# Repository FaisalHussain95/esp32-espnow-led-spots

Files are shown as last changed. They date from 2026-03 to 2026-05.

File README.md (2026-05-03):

# DIY Smart LED Spot Replacement

Replacing 13 cheap 220V ceiling spots with custom COB LED units — dimmable, Home Assistant integrated, actively cooled, and wirelessly controlled over ESP-NOW.

```mermaid
graph LR
    HA[🏠 Home Assistant]

    subgraph wifi_net[IoT WiFi network]
        BR[WiFi Bridge\nESP32-C3 SuperMini\nWiFi mode]
    end

    subgraph espnow_net[ESP-NOW ch11 — AES-128 — no WiFi]
        MA[Master\nESP32-C3 SuperMini]
        S1[Spot 1\nESP32-C3]
        S2[Spot 2\nESP32-C3]
        SN[Spot 3…13\nESP32-C3]
        MA <-->|ESP-NOW| S1
        MA <-->|ESP-NOW| S2
        MA <-->|ESP-NOW| SN
    end

    HA <-->|MQTT| BR
    BR <-->|UART 115200| MA
```

---

## The problem

I have 13 recessed spots installed across my ceiling. They were cheap 220V AC units with no heatsink — just a bare aluminium PCB glued to a plastic shell.

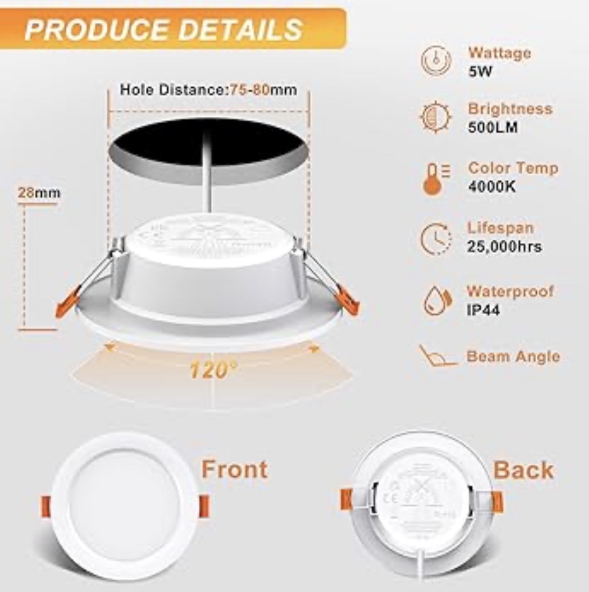
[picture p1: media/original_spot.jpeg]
Original spot


Opening one up tells the whole story: the driver circuit runs directly off mains voltage with no thermal management whatsoever.

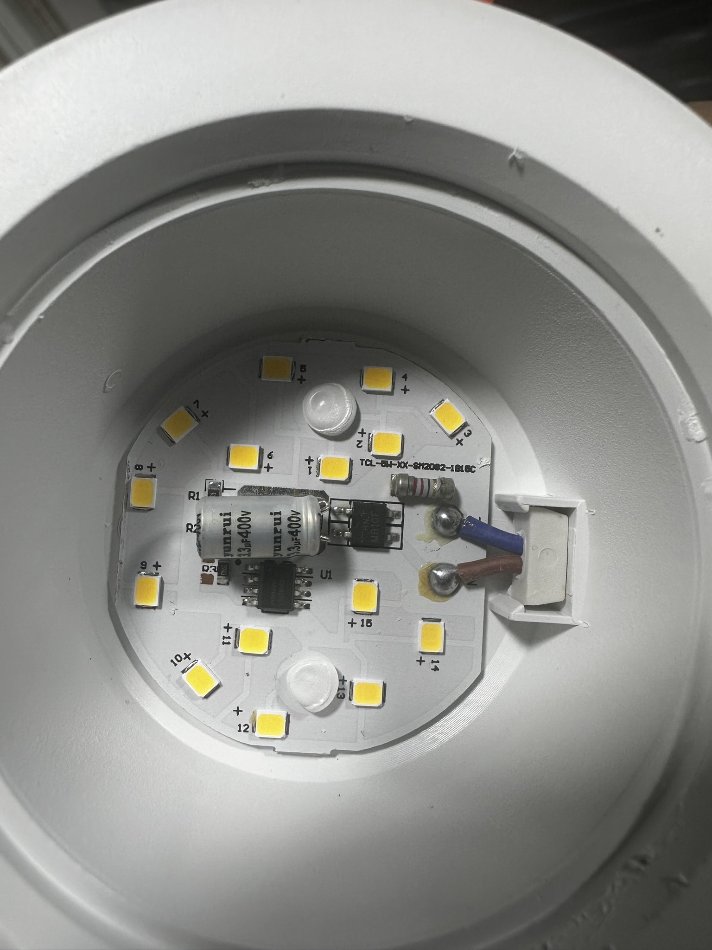
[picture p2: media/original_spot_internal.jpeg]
Original spot internals


After about 5000 hours one by one they started dying from overheating. Rather than buying the same thing again, I decided to rebuild them properly.

---

## The goals

- **Reuse the existing shells** — no new ceiling holes
- **Use COB LEDs from stock** — 5W COB with a proper heatsink and active cooling to make them last
- **Dimmable** — the original spots were on/off only
- **Home Assistant integration** — via MQTT
- **OTA updates** — to add effects or fix bugs without a ladder (we already added a pulse effect and smooth fade in/out)
- **No per-spot WiFi** — 13 devices on the IoT network is too much; ESP-NOW keeps them off WiFi entirely

---

## Why not a simpler controller?

The ESP32 is overkill for dimming a light, I know. The constraint was the existing wiring in the ceiling: when it was first installed nobody thought about future upgrades, so we are stuck with the cables already there. Running a new PWM signal cable through the ceiling was not feasible. We needed a device that could receive wireless commands and that I already knew how to program — hence ESP32 + ESP-NOW.

---

## Power: from 220V mains to 24V DC

The original spots each had their own mains driver. The replacement approach uses a single shared 24V DC rail for all spots.

**Power supply: TRACO TSP 180-124 — 24V / 180W**

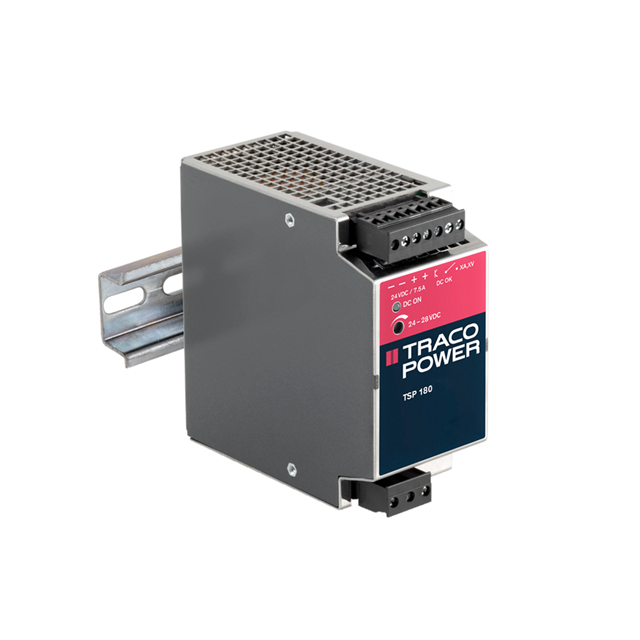
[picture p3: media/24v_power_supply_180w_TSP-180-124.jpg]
Power supply


The supply sits centrally, with two cable runs of 15m each covering all spots.

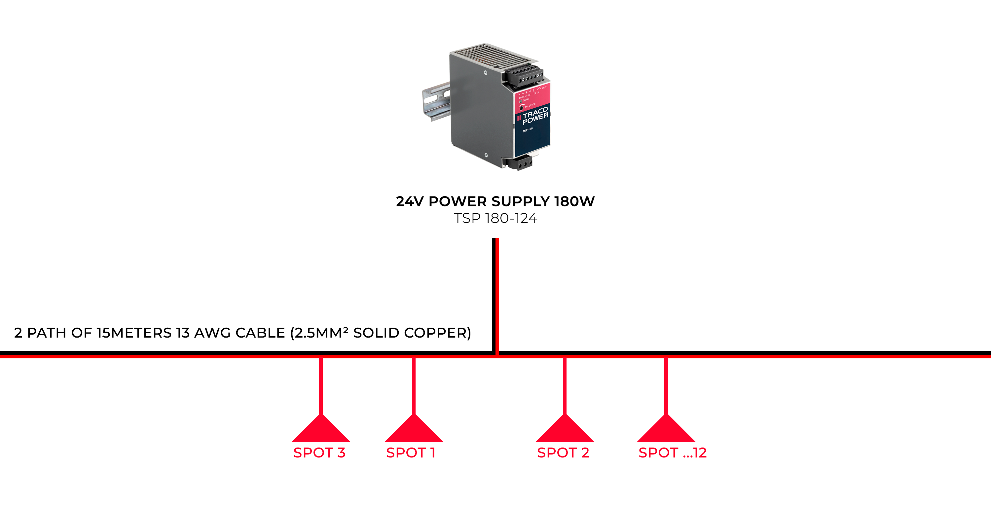
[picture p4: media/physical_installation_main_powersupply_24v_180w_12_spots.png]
Wiring diagram


### Cable sizing

Existing cable: 2.5mm² solid copper (13 AWG), already in the ceiling (previously carrying 220V).

- COB LED: ~7W max, running at PWM 160/255 → ~4.4W effective
- ESP32-C3: ~0.5W
- Budget per spot: **~12W to be safe** → total load: 13 × 12W = **156W / 24V = 6.5A** across the full 30m run
- Per 15m path: **max ~3A**

Using a [wire size calculator](https://www.omnicalculator.com/physics/wire-size) with 3A over 15m and a 10% voltage drop tolerance, 2.5mm² is sufficient. The cable was already there — we just repurposed it from 220V AC to 24V DC.

---

## The replacement unit

Each spot gets a self-contained module: COB LED + heatsink + fan + NTC + ESP32-C3 + custom PCB.

### COB LED on heatsink

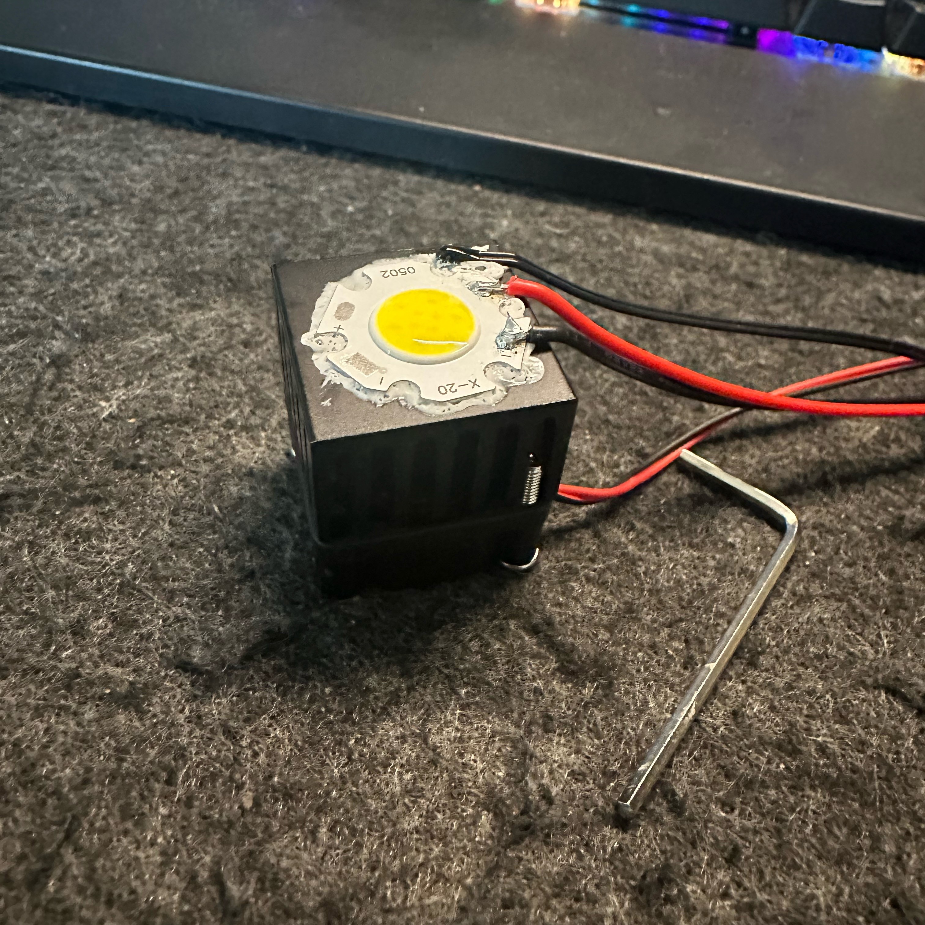
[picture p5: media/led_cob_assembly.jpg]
COB on heatsink


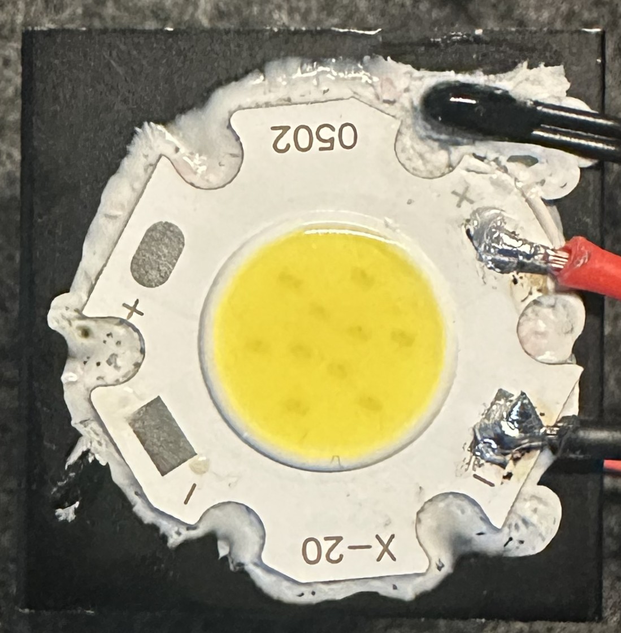
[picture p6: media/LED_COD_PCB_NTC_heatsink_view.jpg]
COB top view


### With fan mounted

The 25×25mm fan sits on top of the heatsink. It is 5V PWM-controlled, kicks in above 45°C and cuts off below 40°C. At normal brightness the fan rarely runs.

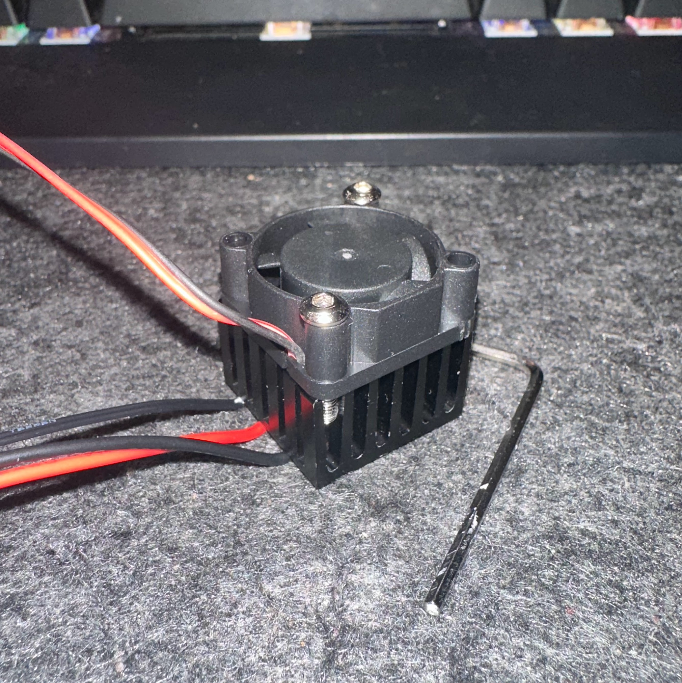
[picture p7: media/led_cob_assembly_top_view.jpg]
Assembly with fan


### NTC thermal protection

An MF52 10kΩ NTC is mounted against the heatsink. The firmware reads it every second and applies progressive PWM throttling at 60°C, a hard floor at 75°C, and alerts the master controller at 85°C.

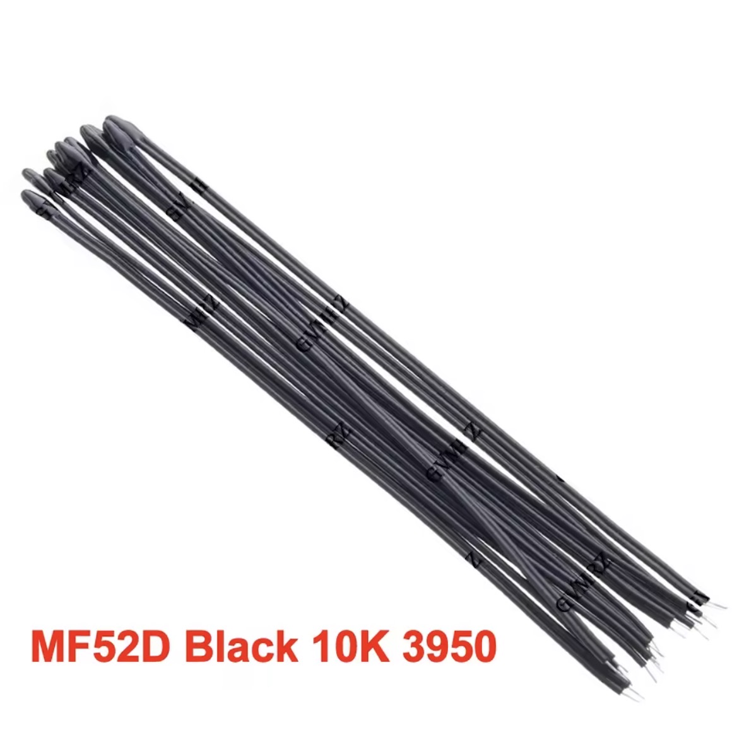
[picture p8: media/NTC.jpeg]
NTC sensor


---

## The PCB

The driver electronics sit on a custom KiCad board that fits inside the spot shell. It carries the MP1584 buck converter (24V → 3.3V), PT4115 LED driver, fan MOSFET, NTC input, and the ESP32-C3 SuperMini.

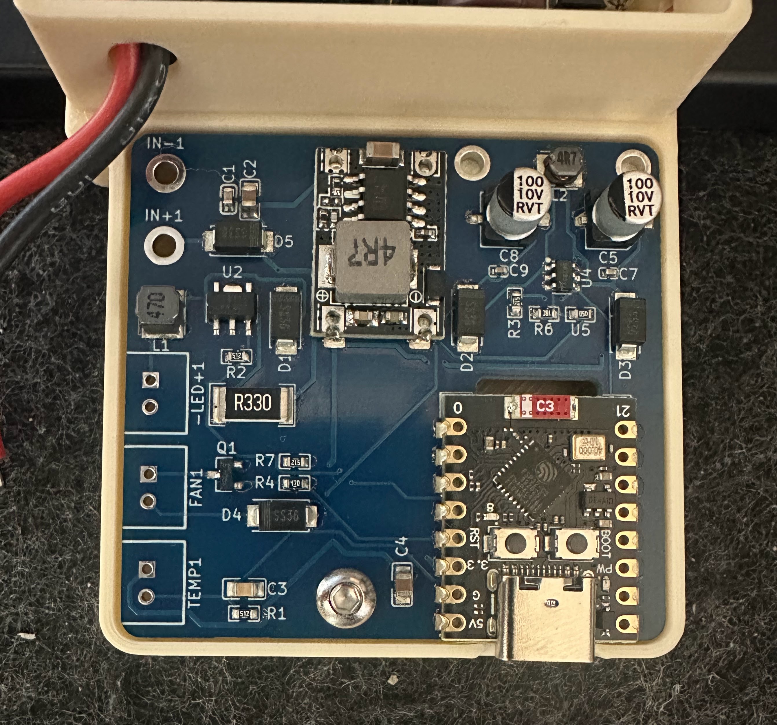
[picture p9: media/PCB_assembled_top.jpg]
PCB top


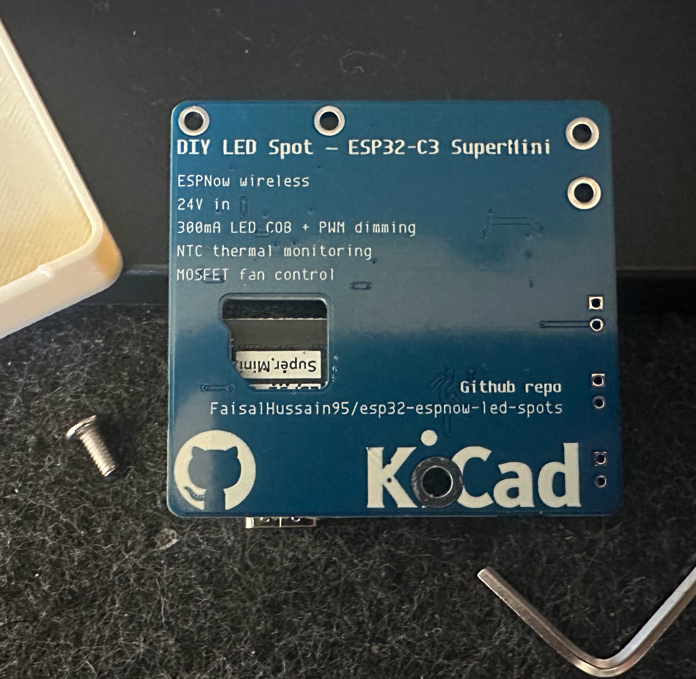
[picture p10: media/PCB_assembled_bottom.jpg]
PCB bottom


**Manufacturing files for JLCPCB** (Gerbers, BOM, CPL) are in [kicad/diy_led_spot/v4/](kicad/diy_led_spot/v4/). The KiCad project itself is in [kicad/diy_led_spot/](kicad/diy_led_spot/).

---

## How it works

Each spot is an ESP32-C3 node. An ESP32-C3 SuperMini acts as master. A second ESP32-C3 SuperMini bridges MQTT to the master over UART. The spots never touch WiFi during normal operation — everything runs over ESP-NOW on a dedicated channel.

```mermaid
sequenceDiagram
    participant HA as Home Assistant
    participant BR as WiFi Bridge<br/>(ESP32-C3 SuperMini)
    participant MA as Master<br/>(ESP32-C3 SuperMini)
    participant SP as Spot × N<br/>(ESP32-C3)
    participant GH as GitHub Releases<br/>(OTA)

    note over SP,MA: ── Boot handshake (ESP-NOW ch11, AES-128) ──
    SP->>MA: MSG_HELLO {spot_id, fw_version}
    alt version OK
        MA->>SP: MSG_ACK
    else version outdated
        MA->>SP: MSG_REJECT + MSG_OTA_NOW {target_version}
        SP->>GH: HTTP GET slave_c3_supermini_vN.bin
        GH-->>SP: firmware binary → flash & reboot
    end

    note over MA: Master reboot → rediscover all spots
    MA->>SP: MSG_WHOIS (broadcast)
    SP->>MA: MSG_HELLO (re-announce)

    note over HA,SP: ── Normal operation ──
    HA->>BR: MQTT homeassistant/led_spots/{id}/set<br/>{"state":"ON","brightness":200}
    BR->>MA: UART frame 0xAA 0x01 spot_id bri cmd 0x55
    MA->>SP: MSG_CMD {spot_id, CMD_TURN_ON, brightness}

    SP-->>MA: MSG_STATUS every 10 s<br/>{spot_id, brightness, temp°C, thermal_state, is_on}
    MA-->>BR: UART frame 0xAA 0x02 spot_id bri temp_hi temp_lo thermal 0x55
    BR-->>HA: MQTT homeassistant/led_spots/{id}/state<br/>{"state":"ON","brightness":200,"temperature":42.3}

    note over SP: ── Thermal protection (on-spot) ──
    SP->>SP: NTC read every 1 s<br/>60°C → throttle PWM<br/>85°C → PWM floor + alert
    SP-->>MA: MSG_STATUS {thermal_state: critical}

    note over HA,GH: ── OTA triggered from HA ──
    HA->>BR: MQTT homeassistant/led_spots/ota/set {"version":30}
    BR->>MA: UART frame 0xAA 0x03 target_version 0x55
    MA->>SP: MSG_OTA_NOW {target_version} (broadcast)
    SP->>GH: HTTP GET slave_c3_supermini_v30.bin
    GH-->>SP: firmware binary → flash & reboot
```

For the full technical details, wiring, firmware architecture, and PCB design see [TECHNICAL.md](TECHNICAL.md).

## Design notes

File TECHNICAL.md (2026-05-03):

# DIY LED Spot Controller

DIY replacement of 10× 220VAC LED spots with custom COB LED + ESP32 controller units.
Each spot has an isolated AC/DC converter, constant-current LED driving via PT4115, NTC thermal monitoring,
and encrypted ESP-NOW wireless control — no WiFi router required for the spots.

---

## System Architecture

```
Home Assistant
     │
     │ MQTT (WiFi)
     │
┌────┴──────────────┐
│  WiFi Bridge      │  ESP32-C3 SuperMini
│                   │  WiFi + MQTT ↔ UART bridge
└────────┬──────────┘
         │ UART1 binary frames (115200 baud)
         │ GPIO6(TX) → GPIO7(RX) (Master)
         │ GPIO7(RX) ← GPIO6(TX) (Master)
┌────────┴──────────┐
│  Master Node      │  ESP32-C3 SuperMini
│                   │  ESP-NOW only
│                   │  Optional: 0.91" SSD1306 128×32 OLED (SDA=GPIO1, SCL=GPIO0)
└────────┬──────────┘
         │ ESP-NOW (PMK encrypted, 2.4GHz)
         │
    ┌────┴────┐
    │         │
  Spot 1   Spot 2 … Spot 10
 ESP32-C3  ESP32-C3  ESP32-C3
 SuperMini SuperMini SuperMini
```

The master (ESP32-C3 SuperMini) runs ESP-NOW only — no WiFi.
The WiFi bridge handles MQTT/HA and translates commands to/from UART binary frames.
This separation avoids ESP-NOW peer drops caused by WiFi channel switching.

---

## Firmware Structure

```
spot_firmware/          — One binary per spot (ESP32-C3 SuperMini)
├── platformio.ini
└── src/
    ├── main.cpp              # Setup, loop, command handler, thermal policy, status LED
    ├── config.h              # Pin defines, thresholds, SPOT_ID, packet structs — edit per unit
    ├── thermal.h/.cpp        # NTC read (32× oversampling), Steinhart-Hart, throttle logic
    ├── dimming.h/.cpp        # LEDC init, setBrightness(), fadeTo()
    ├── espnow_manager.h/.cpp # ESP-NOW init, PMK encryption, HELLO handshake, send/receive
    ├── provisioning.h/.cpp   # PMK + WiFi creds from build_flags → NVS (first boot only)
    └── ota.h/.cpp            # HTTP OTA update from GitHub release URL (5 retries)

master_firmware/        — One binary for the master node (ESP32-C3 SuperMini)
├── platformio.ini
└── src/
    ├── main.cpp              # ESP-NOW master, OLED display, serial CLI, UART bridge
    └── config.h              # Spot MAC table, packet structs, UART pin defines

wifi_bridge_firmware/   — One binary for the WiFi bridge (ESP32-C3 SuperMini)
├── platformio.ini
└── src/
    ├── main.cpp              # WiFi + MQTT ↔ UART bridge, HA MQTT Discovery
    └── config.h              # UART pins, MQTT topic prefix, frame constants
```

**Porting a spot to a new unit:** only change `SPOT_ID` (0x01–0x0A) in `spot_firmware/src/config.h`. The master MAC is read from NVS via `provisioning_get_master_mac()` — it is no longer hardcoded.

---

## Hardware (per spot)

### Power Chain
```
220VAC ──► HLK-PM24 ──► 24VDC ──► PT4115 (CC driver) ──► COB LED (5W)
                    │
                    └──► MP1584 buck ──► 3.3VDC ──► ESP32-C3 SuperMini
                                                          │
                                                     GPIO10 (PWM 10kHz)
                                                          │
                                                     PT4115 DIM pin
```

The HLK-PM24 provides an isolated 24V rail.
The PT4115 is a constant-current buck LED driver — current is set by Rsense, not firmware.
PWM on the DIM pin dims the LED by modulating the driver enable signal.

### Components

| Component | Value / Model | Purpose |
|---|---|---|
| AC/DC converter | HLK-PM24 | 220VAC → 24VDC, 1A, isolated |
| Buck converter | MP1584 module | 24V → 3.3V for ESP32 |
| Microcontroller | ESP32-C3 SuperMini | Control + ESP-NOW wireless |
| LED driver | PT4115 | Constant-current buck driver, DIM pin PWM |
| Current sense | 0.33Ω 1W | Iout = 0.1V / 0.33Ω ≈ 303mA |
| Freewheeling diode | 1N4007 | Across COB LED (buck topology) |
| Thermal sensor | NTC 10kΩ 0402, B=3950 | Mounted on COB PCB |
| NTC divider | 5.1kΩ fixed to GND | NTC on 3.3V side |
| ADC filter | 100nF ceramic to GND | On ADC signal wire, noise filtering |

### PT4115 Wiring
```
24V ──► PT4115 VIN
        PT4115 SW ──► inductor ──► COB+ ──► COB- ──► PT4115 CS ──► 0.33Ω ──► GND
ESP32 GPIO10 ──► PT4115 DIM   (PWM 10kHz, 0–100% duty = 0–full current)
```

### NTC Wiring
```
3.3V
 │
[NTC 10kΩ]          ← mounted on COB PCB, wired back to ESP32 via cable
 │
 ├──► GPIO3 (ADC1_CH3)
 │         │
 │       [100nF] ──► GND    ← on ESP32 PCB end, filters cable noise
 │
[5.1kΩ]
 │
GND
```

- NTC on the 3.3V side; formula: `r_ntc = R_pullup × (ADC_MAX − adc) / adc`
- 32× ADC oversampling + Steinhart-Hart Beta equation
- **ADC quirk (ESP32 Arduino core):** call a dummy `analogRead(pin)` before `analogSetPinAttenuation()` — otherwise attenuation doesn't apply and the ADC reads 0

### GPIO Pin Mapping

#### ESP32-C3 SuperMini (spot node — final)
| Function | GPIO | Notes |
|---|---|---|
| PWM → PT4115 DIM | GPIO10 | LEDC 10kHz 8-bit, no ADC, no strapping conflict |
| NTC ADC | GPIO3 | ADC1_CH3 — safe with ESP-NOW active (ADC1 only) |
| Status LED | GPIO8 | Onboard blue LED, **active LOW** |

#### Master / Bridge (ESP32-C3 SuperMini)
| Function | GPIO | Notes |
|---|---|---|
| UART1 TX (to bridge/master) | GPIO6 | Cross-connected TX→RX |
| UART1 RX (from bridge/master) | GPIO7 | Cross-connected RX←TX |
| OLED SDA (master only, optional) | GPIO1 | I2C, 0.91" SSD1306 128×32 |
| OLED SCL (master only, optional) | GPIO0 | I2C |

#### ESP32 WROVER (prototype only)
| Function | GPIO | Notes |
|---|---|---|
| PWM → PT4115 DIM | GPIO18 | LEDC 10kHz 8-bit |
| NTC ADC | GPIO34 | Input-only ADC1 channel |
| Status LED | GPIO2 | Onboard LED, active HIGH |

---

## Thermal Protection

### PWM limits
| Constant | Value | Reason |
|---|---|---|
| `PWM_MAX` | 160 | ~5W operating point for COB LED |
| `PWM_MIN_FLOOR` | 20 | Minimum allowed in throttle/critical states |

The master can send brightness 0–255, but the spot clamps the output to `PWM_MAX` (160) before passing it to the LEDC peripheral.

### Thermal states

| Temperature | State | Action |
|---|---|---|
| < 60°C | NORMAL | Full PWM authority (capped at `PWM_MAX`=160) |
| 60–75°C | THROTTLING | Linear ramp-down from requested brightness to `PWM_MIN_FLOOR` (20) |
| 75–85°C | THROTTLING | Hard floor: output clamped to `PWM_MIN_FLOOR` (20) |
| > 85°C | CRITICAL | Clamped to `PWM_MIN_FLOOR` + immediate ESP-NOW alert to master |

### Status LED patterns (GPIO8, active LOW)
| State | Pattern |
|---|---|
| NORMAL | 1s on / 2s off |
| THROTTLING | Solid ON |
| CRITICAL | 100ms on / 100ms off (rapid blink) |
| NTC fault | CRITICAL pattern |

---

## ESP-NOW Protocol

### Encryption
All unicast packets are PMK-encrypted (AES-128).
The PMK is set in `platformio.ini` `build_flags`, written to NVS on first boot, and survives OTA flashes.
It is never stored in the released binary.

```
esp_now_set_pmk(pmk)     ← called on both master and spots
peer.encrypt = true      ← on all unicast peers
peer.lmk = pmk           ← PMK used as LMK — single shared key, no 6-peer hardware limit
```

Broadcast peer (FF:FF:FF:FF:FF:FF) is unencrypted — required for OTA broadcast to reach all spots.

### Packet Format
Every packet starts with a 9-byte header:

```c
typedef struct __attribute__((packed)) {
    uint8_t msg_type;    // MSG_* value
    uint8_t fw_version;  // sender's firmware version
    uint8_t attempt;     // OTA retry count (0 for non-OTA)
    uint8_t mac[6];      // sender MAC (for dynamic peer registration)
} espnow_header_t;
```

Full packet types:

| Packet type | Structure |
|---|---|
| `espnow_cmd_packet_t` | `espnow_header_t` + `esp_now_cmd_t` |
| `espnow_status_packet_t` | `espnow_header_t` + `esp_now_status_t` |
| `espnow_ota_packet_t` | `espnow_header_t` + `uint8_t target_version` |

### Message Types
| Value | Name | Direction | Description |
|---|---|---|---|
| 0x01 | MSG_HELLO | Spot → Master | Boot announce — fw_version + MAC |
| 0x02 | MSG_ACK | Master → Spot | Version OK, proceed normally |
| 0x03 | MSG_REJECT | Master → Spot | Version outdated, OTA incoming |
| 0x04 | MSG_OTA_NOW | Master → All | Broadcast OTA trigger with target version |
| 0x05 | MSG_OTA_FAILED | Spot → Master | OTA attempt failed |
| 0x06 | MSG_WHOIS | Master → All | Broadcast on master boot — spots re-send MSG_HELLO |
| 0x10 | MSG_CMD | Master → Spot | LED command |
| 0x11 | MSG_STATUS | Spot → Master | Periodic status report |

### LED Commands (inside MSG_CMD)
| Value | Name | Description |
|---|---|---|
| 0x01 | CMD_SET_BRIGHTNESS | Set brightness 0–255 |
| 0x02 | CMD_TURN_ON | Turn on (with brightness, 300ms fade) |
| 0x03 | CMD_TURN_OFF | Turn off (500ms fade) |
| 0x04 | CMD_REQUEST_STATUS | Force immediate status reply |
| 0x05 | CMD_PULSE | Looping pulse (param = duration in ms, 0 = 500ms default) |

### Boot Handshake
```
Spot boots
  → provisioning_init(): PMK + WiFi loaded from NVS (written from build_flags on first boot)
  → espnow_init(): set PMK, register master as encrypted peer, send MSG_HELLO

Master receives MSG_HELLO from spot:
  → if MAC not yet registered: addPeer() with encryption
  → if spot.fw_version >= required_fw_version: send MSG_ACK
  → else: send MSG_REJECT + broadcast MSG_OTA_NOW

Spot receives MSG_ACK        → normal operation
Spot receives MSG_REJECT / MSG_OTA_NOW → ota_start(target_version)
```

---

## OTA Updates

Spot nodes fetch firmware over HTTP from GitHub releases. Master and WiFi bridge must be flashed manually via USB.

### OTA URL
```
https://github.com/FaisalHussain95/esp32-espnow-led-spots/releases/download/v<N>/slave_c3_supermini_v<N>.bin
```

### OTA sequence
```
1. Spot connects to WiFi (SSID/password from NVS)
2. HTTP GET firmware .bin from GitHub releases URL
3. HTTPUpdate.update() flashes new firmware to inactive OTA slot
4. ESP.restart() — boots into new firmware
5. On failure: send MSG_OTA_FAILED, wait 10s, retry
6. After 5 failures: stay on current firmware, log error
```

### Triggering OTA

**Via serial (Master):**
```
version 30
```

**Via MQTT (Home Assistant):**
```
Topic:   homeassistant/led_spots/ota/set
Payload: {"version":30}
```

---

## UART Bridge

Binary frame protocol between master (ESP32-C3 SuperMini) and WiFi bridge (ESP32-C3 SuperMini).

### Pin connections
| Master C3 | Bridge C3 |
|---|---|
| GPIO6 TX | GPIO7 RX |
| GPIO7 RX | GPIO6 TX |
| GND | GND |

### Frame format (115200 baud, 8N1)

| Frame | Size | Bytes |
|---|---|---|
| Command (HA → spot) | 6 | `0xAA 0x01 spot_id brightness command 0x55` |
| Status (spot → HA) | 9 | `0xAA 0x02 spot_id brightness temp_hi temp_lo thermal_state is_on 0x55` |
| Version/OTA (HA → master) | 4 | `0xAA 0x03 target_version 0x55` |

Temperature in STATUS frames is `int16` in 0.1°C units, big-endian (e.g. 24.3°C = 243 = `0x00 0xF3`).

---

## Home Assistant Integration

The WiFi bridge publishes MQTT Discovery payloads on connect — spots appear automatically as light entities in HA.

| Entity | MQTT Topic |
|---|---|
| Light command | `homeassistant/led_spots/<id>/set` |
| Light state | `homeassistant/led_spots/<id>/state` |
| HA Discovery config | `homeassistant/light/led_spot_<id>/config` (retained) |
| OTA trigger | `homeassistant/led_spots/ota/set` |

**Command payload:** `{"state":"ON","brightness":200}`

**State payload:** `{"state":"ON","brightness":200,"temperature":24.3,"thermal_state":"normal"}`

---

## Master Serial CLI

Connect to Master (ESP32-C3 SuperMini) on 115200 baud:

```
on    <spot|all> [bri]        Turn on (brightness 0–255, default 255)
off   <spot|all>              Turn off
dim   <spot|all> <bri>        Set brightness 0–255
pulse <spot|all> [bri] [ms]   Pulse loop (default bri=100, ms=500)
status <spot|all>              Request immediate status reply
version <N>                    Set required fw version, broadcast OTA to all spots
help                           List commands
```

Examples:
```
on all         → turn on all spots at full brightness
dim 3 128      → set spot 3 to ~50% brightness
version 30     → push OTA firmware v30 to all spots
```

---

## Provisioning (First-Time Setup)

Credentials are injected into all three `platformio.ini` files by the `inject_credentials.js` script.
On first boot they are written to NVS (flash, separate partition from firmware) and survive all subsequent OTA updates.

### 1. Copy and fill in `.env`

```bash
cp .env.exemple .env
```

```ini
# .env
PMK_INPUT=your-secret-passphrase   # hashed to a 32-char hex PMK

WIFI_SSID=YourNetwork              # used only for OTA HTTP downloads
WIFI_PASSWORD=YourPassword

MQTT_BROKER_IP=192.168.1.x         # WiFi bridge only — leave blank if unused
MQTT_PORT=1883
MQTT_USER=
MQTT_PASSWORD=
```

### 2. Inject credentials into all platformio.ini files

```bash
node --env-file=.env inject_credentials.js
```

This updates `build_flags` in `spot_firmware/`, `master_firmware/`, and `wifi_bridge_firmware/` in one shot.

### 3. Flash

```bash
cd spot_firmware        && pio run --target upload
cd master_firmware      && pio run --target upload
cd wifi_bridge_firmware && pio run --target upload
```

> **PMK must be identical** on all spots and the master.
> WiFi credentials on spots are used only for OTA HTTP downloads — not for normal operation.

### 4. Provision each spot via serial (production workflow)

After flashing, open a serial monitor on the spot (115200 baud) and send:

```
PROV <spot_id>|<wifi_ssid>|<wifi_password>|<pmk_hex>
```

Example:
```
PROV 3|MyWifi|MyPassword|a1b2c3d4e5f6a1b2c3d4e5f6a1b2c3d4
```

- `spot_id`: decimal integer 1–254
- `pmk_hex`: 32-char lowercase hex string (same value as `PMK_INPUT` hashed by `inject_credentials.js`)
- The spot writes all values to NVS and reboots immediately — no second flash needed

On reboot the spot loads credentials from NVS and the build_flags values are ignored.

> **To reprovision an already-flashed unit:** send a new `PROV` command at any time — it overwrites NVS and reboots.
>
> **Legacy method (still works):** add `-DCONFIG_PROV_FORCE_RESET=1` to `build_flags`, flash once, then remove the flag and reflash.

---

## GitHub Actions CI

Pushing a git tag builds all three firmware targets and creates a GitHub release with `.bin` files attached.

```bash
git tag v30
git push origin v30
# Builds: slave_c3_supermini_v30.bin  master_c3_supermini_v30.bin  wifi_bridge_v30.bin
# Creates GitHub release with all three files
```

The spot OTA URL is constructed automatically from the tag version number.

> Release binaries are built with placeholder credentials. Set your own PMK and WiFi credentials in `platformio.ini` before flashing.

---

## Heatsink

Selected: **25×25mm pin-grid, 6×6 array, 13mm tall** (~19°C/W).

| Heatsink | θsa (°C/W) | T_junction @25°C ambient | T_junction @50°C ambient |
|---|---|---|---|
| 20×20×6mm flat | ~102 | ~131°C ✗ | ~156°C ✗ |
| 20×20×10mm flat | ~83 | ~112°C ✓ | ~137°C ✗ |
| **25×25 pin-grid 6×6** | **~19** | **~49°C ✓✓** | **~74°C ✓✓** |

- COB max junction temp: 125°C
- Heat at junction at 5W: ~1W (remainder is light)
- **51°C margin at 50°C ambient ✓✓**

Thermal chain: `P_heat → [θjc ~4°C/W] → [θcs paste ~0.3°C/W] → [θsa ~19°C/W] → ambient`

---

## Enclosures (3D Printed)

| Part | Material | Reason |
|---|---|---|
| COB + heatsink housing | PC (Polycarbonate) | Near heat source, ~110–120°C rated |
| Controller side (ESP32 + PCB) | PLA | Thermally isolated from COB side |
| Cable routing clips | PLA / PETG | Ambient temperature only |

PC print settings: nozzle 260–280°C, bed 90–100°C, cooling fan off, dry filament at 80°C for 4–6h before printing.

---

## PCB & Manufacturing

- Design tool: **KiCad** — project at `kicad/diy_led_spot/`
- Gerbers exported to `kicad/diy_led_spot/` (ready for JLCPCB upload)
- Strategy: design 1 unit → validate → order ×10
- Assembly: hybrid — JLCPCB SMT for passives, hand-solder HLK-PM24 + ESP32-C3

### KiCad Project Files
```
kicad/diy_led_spot/
├── diy_led_spot.kicad_sch    # Schematic
├── diy_led_spot.kicad_pcb    # PCB layout
├── diy_led_spot.kicad_pro    # Project file
└── diy_led_spot_step5-*.gbr  # Exported Gerbers (F_Cu, B_Cu, Mask, Silkscreen, Edge_Cuts)
```

### Cost Estimate (10 units)
| Scenario | Estimated Total |
|---|---|
| Full DIY hand-soldered | ~$70–80 |
| Hybrid JLCPCB SMT + hand-solder | ~$100–110 |

---

## NVS Layout

| Firmware | Namespace | Key | Type | Content |
|---|---|---|---|---|
| Spot | `espnow` | `pmk` | bytes (16) | Shared PMK |
| Spot | `espnow` | `master_mac` | bytes (6) | Master ESP-NOW MAC (written by v29, read from v30+) |
| Spot | `wifi` | `ssid` | string | WiFi SSID (OTA only) |
| Spot | `wifi` | `password` | string | WiFi password (OTA only) |
| Master | `espnow` | `pmk` | bytes (16) | Shared PMK |

---

## Validation Workflow

1. Validate NTC divider + RC filter in **Falstad** (falstad.com/circuit)
2. Prototype firmware on **WROVER** before committing to ESP32-C3 SuperMini boards
3. Schematic + PCB layout in **KiCad** (`kicad/diy_led_spot/`)
4. Export Gerbers → upload to **JLCPCB**, order prototype → validate → order ×10

---

## Next Steps

- [x] Write spot node firmware (dimming, thermal protection, ESP-NOW)
- [x] Write master controller firmware (ESP32-C3 SuperMini + optional OLED + serial CLI)
- [x] Port spot firmware to ESP32-C3 SuperMini
- [x] Add WiFi bridge (UART ↔ MQTT) for Home Assistant integration
- [x] ESP-NOW PMK encryption + boot handshake protocol
- [x] OTA update system (HTTP from GitHub releases, 5-retry)
- [x] GitHub Actions CI (auto-build + release on git tag push)
- [x] KiCad schematic + PCB layout (`kicad/diy_led_spot/`)
- [x] Gerbers exported (ready for JLCPCB)
- [ ] Order prototype PCBs → validate
- [ ] Order ×10 production run
- [ ] Print test enclosures (PLA prototype, then PC for COB side)
- [ ] Validate thermal performance on first assembled unit
- [x] Active cooling: 5V 25mm fan via MT3608 boost converter (GPIO5 EN) + AO3400 MOSFET (GPIO4) — fan ON above 45°C, OFF below 40°C (hysteresis), forced ON on NTC fault. PCB rev includes MT3608 + MOSFET footprint.
- [x] Default boot state: ON — spot lights up immediately when mains power is applied; mains switch acts as physical on/off control without requiring master commands.
- [x] Migrate master and WiFi bridge from TTGO LoRa32 / generic ESP32 to ESP32-C3 SuperMini
- [x] Master MAC provisioning via NVS (no more hardcoded MASTER_MAC in spot firmware)
- [x] TX power cap at 13 dBm + FreeRTOS yield in master loop (heat reduction)

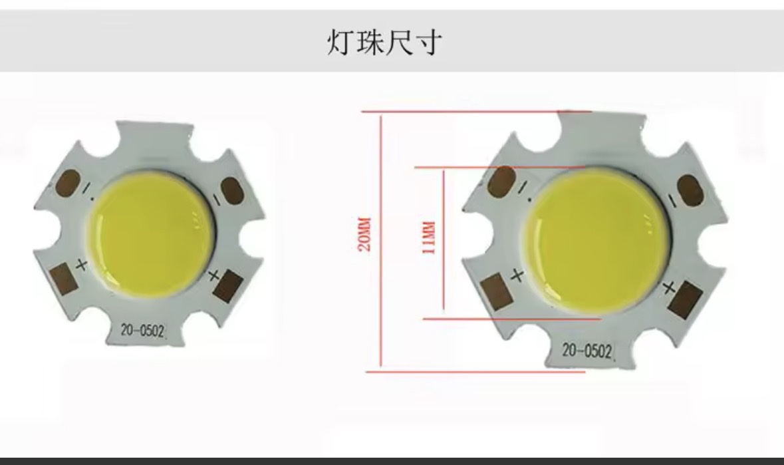
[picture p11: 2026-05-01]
media/led_cob_7w.jpeg

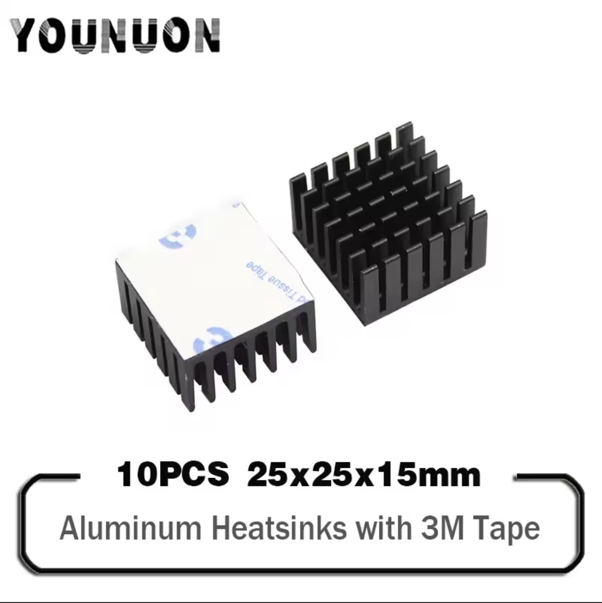
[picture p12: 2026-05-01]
media/heatsink_25x25.jpeg

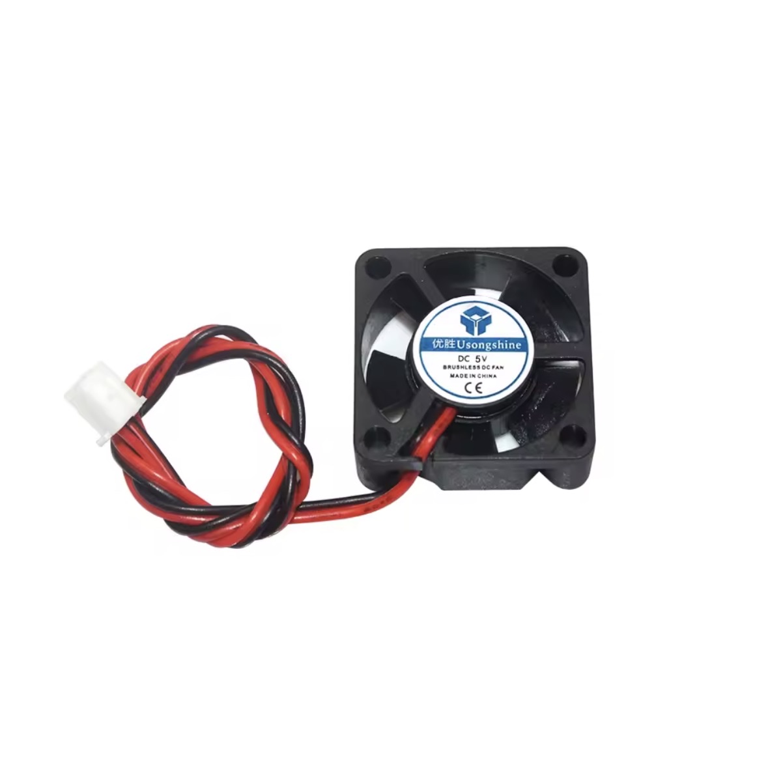
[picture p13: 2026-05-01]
media/fan_5v_2525.jpeg

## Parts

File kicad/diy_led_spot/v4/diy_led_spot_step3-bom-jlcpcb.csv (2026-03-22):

Comment | Designator | Footprint | LCSC Part #
100nF | C7 C9 | C0402 | C307331
100uF | C5 C8 | CAP-SMD_BD5.0-L5.3-W5.3-LS6.3-FD | C72473
15kΩ | R6 | R0603 | C2906995
110kΩ | U5 | R0603 | C2906984
0.33 1W | Rs1 | R2512 | C19269965
100nF 50V | C3 | C0805 | C476766
100pF 50V | C1 | C0603 | C14858
22uF 35V | C2 C4 | C0805 | C6119901
47uH 800mA | L1 | IND-SMD_L4.0-W4.0_FNR40XXS | C167888
5.1kΩ 100mW | R1 R2 R3 R7 | R0603 | C23186
AO3400A | Q1 | SOT-23-3_L2.9-W1.3-P1.90-LS2.4-BR | C347475
MT3608 | U4 | SOT-23-6_L2.9-W1.6-P0.95-LS2.8-BL | C84817
PT4115 | U2 | SOT-89-5_L4.5-W2.5-P1.50-LS4.5-BR | C347356
RC0603FR-0747RL | R4 | R0603 | C114623
SM3521-4R7MT | L2 | IND-SMD_L3.5-W3.0 | C35602
SS36 | D1 D2 D3 D4 D5 | SMA_L4.3-W2.6-LS5.2-RD | C16015

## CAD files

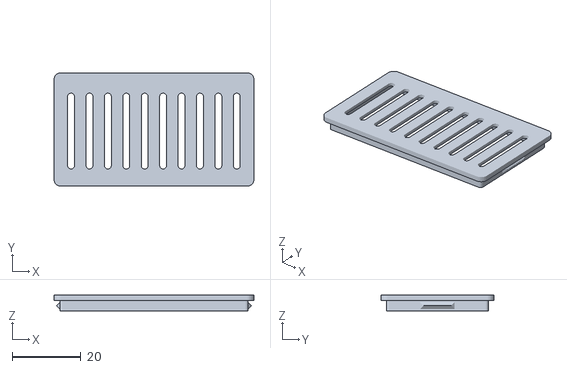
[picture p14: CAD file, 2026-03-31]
kicad/diy_led_spot/diy_led_case_top.stl
58.0 x 32.9 x 4.50

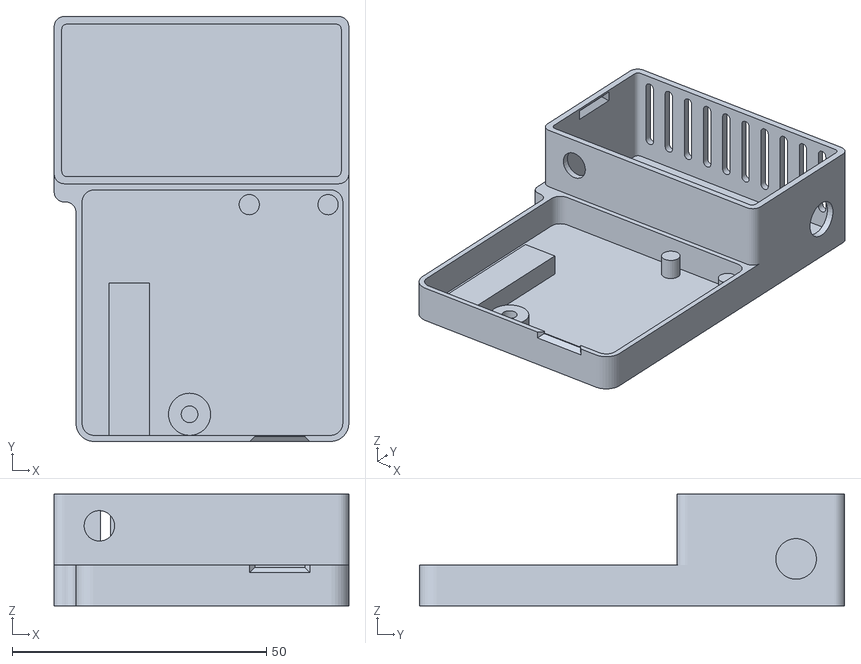
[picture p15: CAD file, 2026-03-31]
kicad/diy_led_spot/diy_led_case_bottom.stl
58.0 x 83.6 x 22.0

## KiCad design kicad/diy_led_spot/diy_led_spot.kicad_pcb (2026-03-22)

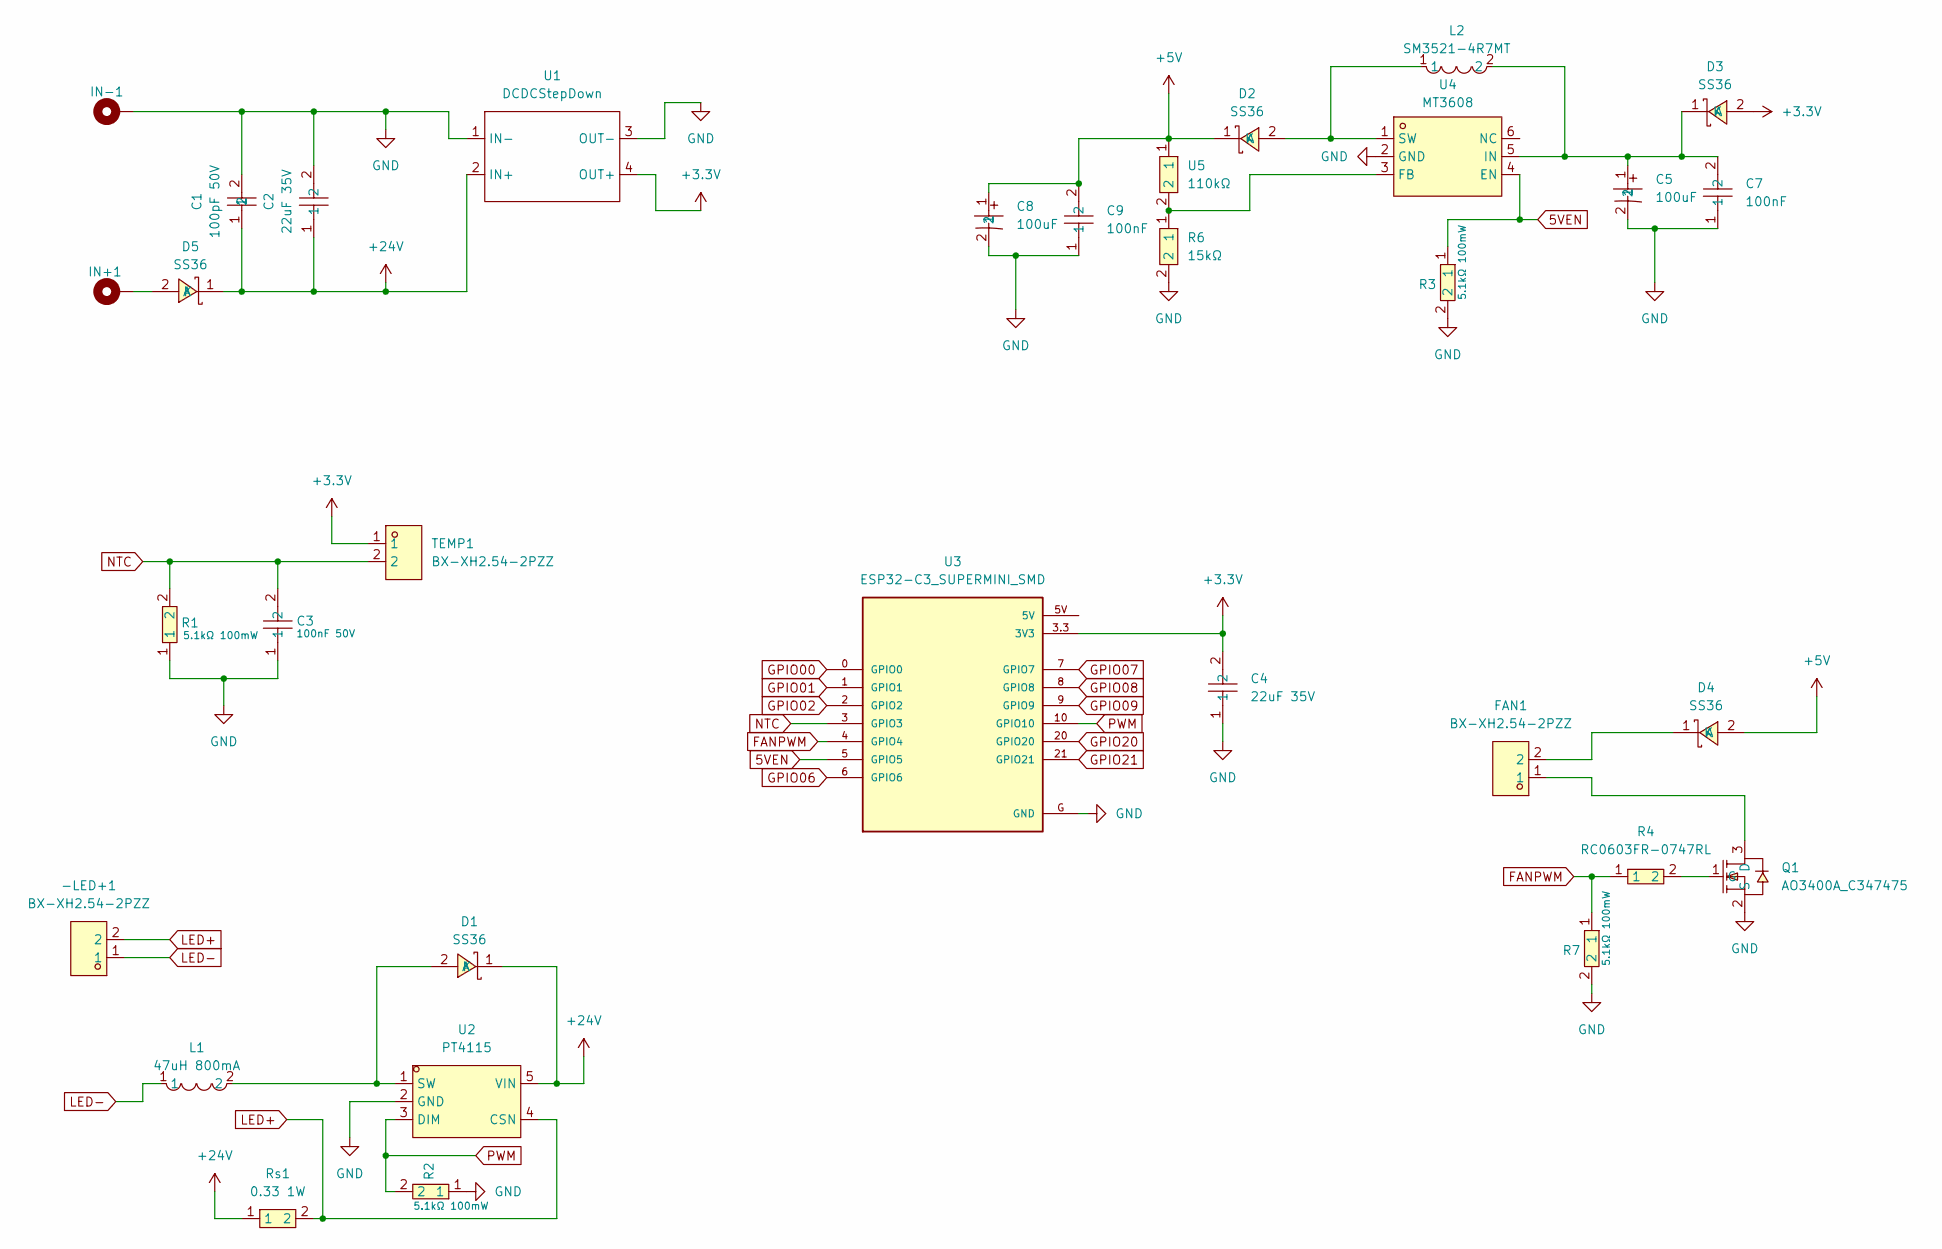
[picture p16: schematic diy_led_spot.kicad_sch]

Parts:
-LED+1: BX-XH2.54-2PZZ; CONN-TH_2P-P2.50_BX-XH2.54-2PZZ; LCSC Part C18077833
C1: 100pF 50V; C0603; LCSC Part C14858
C2, C4: 22uF 35V; C0805; LCSC Part C6119901
C3: 100nF 50V; C0805; LCSC Part C476766
C5, C8: 100uF; CAP-SMD_BD5.0-L5.3-W5.3-LS6.3-FD; LCSC Part C72473
C7, C9: 100nF; C0402; LCSC Part C307331
D1, D2, D3, D4, D5: SS36; SMA_L4.3-W2.6-LS5.2-RD; LCSC Part C16015
FAN1: BX-XH2.54-2PZZ; CONN-TH_2P-P2.50_BX-XH2.54-2PZZ; LCSC Part C18077833
IN+1: MountingHole_Pad; MountingHole_2.2mm_M2_DIN965_Pad_TopBottom
IN-1: MountingHole_Pad; MountingHole_2.2mm_M2_DIN965_Pad_TopBottom
L1: 47uH 800mA; IND-SMD_L4.0-W4.0_FNR40XXS; LCSC Part C167888
L2: SM3521-4R7MT; IND-SMD_L3.5-W3.0; LCSC Part C35602
Q1: AO3400A_C347475; SOT-23-3_L2.9-W1.3-P1.90-LS2.4-BR; LCSC Part C347475
R1, R2, R3, R7: 5.1kΩ 100mW; R0603; LCSC Part C23186
R4: RC0603FR-0747RL; R0603; LCSC Part C114623
R6: 15kΩ; R0603; LCSC Part C2906995
Rs1: 0.33 1W; R2512; LCSC Part C19269965
TEMP1: BX-XH2.54-2PZZ; CONN-TH_2P-P2.50_BX-XH2.54-2PZZ; LCSC Part C18077833
U1: DCDCStepDown; DCDCBuck5V-30V_To_3.3V_5V_9V_12V_3A
U2: PT4115; SOT-89-5_L4.5-W2.5-P1.50-LS4.5-BR; LCSC Part C347356
U3: ESP32-C3_SUPERMINI_SMD; MODULE_ESP32-C3_SUPERMINI
U4: MT3608; SOT-23-6_L2.9-W1.6-P0.95-LS2.8-BL; LCSC Part C84817
U5: 110kΩ; R0603; LCSC Part C2906984

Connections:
5VEN: R3.1, U3.5 (GPIO5), U4.4 (EN)
+3.3V: C4.2, D3.2 (A), TEMP1.1, U1.4 (OUT+), U3.3.3 (3V3)
+5V: C8.1, C9.2, D2.1 (K), D4.2 (A), U5.1
+24V: C1.1, C2.1, D1.1 (K), D5.1 (K), Rs1.1, U1.2 (IN+), U2.5 (VIN)
FANPWM: R4.1, R7.1, U3.4 (GPIO4)
GND: C1.2, C2.2, C3.1, C4.1, C5.2, C7.1, C8.2, C9.1, IN-1.1, Q1.2 (S), R1.1, R2.1, R3.2, R6.2, R7.2, U1.1 (IN-), U1.3 (OUT-), U2.2 (GND), U3.G (GND), U4.2 (GND)
GPIO00: U3.0 (GPIO0)
GPIO01: U3.1 (GPIO1)
GPIO02: U3.2 (GPIO2)
GPIO06: U3.6 (GPIO6)
GPIO07: U3.7 (GPIO7)
GPIO08: U3.8 (GPIO8)
GPIO09: U3.9 (GPIO9)
GPIO20: U3.20 (GPIO20)
GPIO21: U3.21 (GPIO21)
LED+: -LED+1.2, Rs1.2, U2.4 (CSN)
LED-: -LED+1.1, L1.1
NTC: C3.2, R1.2, TEMP1.2, U3.3 (GPIO3)
unnamed: D1.2 (A), L1.2, U2.1 (SW)
unnamed: D2.2 (A), L2.1, U4.1 (SW)
unnamed: C5.1, C7.2, D3.1 (K), L2.2, U4.5 (IN)
unnamed: D4.1 (K), FAN1.2
unnamed: D5.2 (A), IN+1.1
unnamed: FAN1.1, Q1.3 (D)
unnamed: Q1.1 (G), R4.2
unnamed: R6.1, U4.3 (FB), U5.2
PWM: R2.2, U2.3 (DIM), U3.10 (GPIO10)

Board: 2 copper layers, 33 parts (0 on the bottom side), 18 nets, no tracks yet.

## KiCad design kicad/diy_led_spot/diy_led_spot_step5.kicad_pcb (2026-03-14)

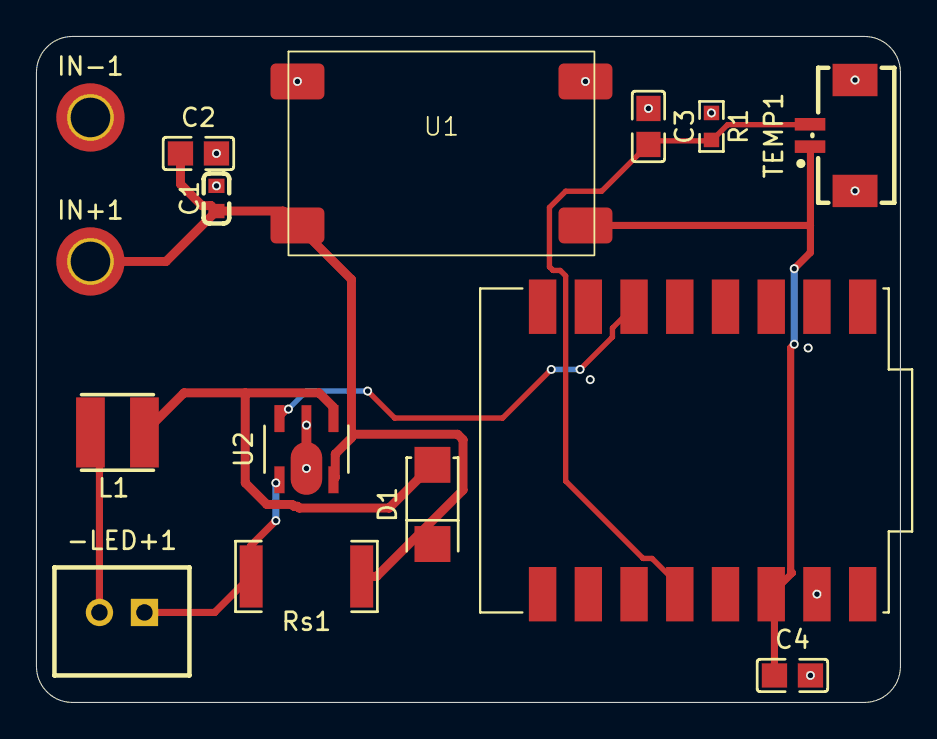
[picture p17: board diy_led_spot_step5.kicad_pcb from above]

Board: 2 copper layers, 48.0 x 37.0 mm, 15 parts (0 on the bottom side), 8 nets.

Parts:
-LED+1: BX-XH2.54-2PZZ; CONN-TH_2P-P2.50_BX-XH2.54-2PZZ
C1: 100pF 50V; C0603
C2, C4: 22uF 35V; C0805
C3: 100nF 50V; C0805
D1: SS36; SMA_L4.3-W2.6-LS5.2-RD
IN+1: MountingHole_Pad; MountingHole_2.2mm_M2_DIN965_Pad_TopBottom
IN-1: MountingHole_Pad; MountingHole_2.2mm_M2_DIN965_Pad_TopBottom
L1: 47uH 800mA; IND-SMD_L4.0-W4.0_FNR40XXS
R1: 5.1kΩ 100mW; R0603
Rs1: 0.33 1W; R2512
TEMP1: MX1.25-2P; CONN-SMD_2P-P1.25_XUNPU_WAFER-MX1.25-2PWB
U1: DCDCStepDown; DCDCBuck5V-30V_To_3.3V_5V_9V_12V_3A
U2: PT4115; SOT-89-5_L4.5-W2.5-P1.50-LS4.5-BR
U3: ESP32-C3_SUPERMINI_SMD; MODULE_ESP32-C3_SUPERMINI

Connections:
+3.3V: C4.2, TEMP1.1, U1.4 (OUT+), U3.3.3 (3V3)
+24V: C1.1, C2.1, D1.1 (K), IN+1.1, Rs1.1, U1.2 (IN+), U2.5 (VIN)
GND: C1.2, C2.2, C3.1, C4.1, IN-1.1, R1.1, TEMP1.3, TEMP1.4, U1.1 (IN-), U1.3 (OUT-), U2.2 (GND), U3.G (GND)
NTC: C3.2, R1.2, TEMP1.2, U3.3 (GPIO3)
unnamed: -LED+1.2, L1.1
unnamed: D1.2 (A), L1.2, U2.1 (SW)
unnamed: -LED+1.1, Rs1.2, U2.4 (CSN)
PWM: U2.3 (DIM), U3.10 (GPIO10)

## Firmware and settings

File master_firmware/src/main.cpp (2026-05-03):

#include <Arduino.h>
#include <WiFi.h>
#include <esp_now.h>
#include <esp_wifi.h>
#include <Preferences.h>
#include <HTTPUpdate.h>
#if ENABLE_OLED
#include <Wire.h>
#include <Adafruit_GFX.h>
#include <Adafruit_SSD1306.h>
#endif
#include "config.h"

// ─── PMK (loaded from NVS on boot) ────────────────────────────────────────────
static uint8_t _pmk[16] = {};

// Required slave firmware version — always matches compiled FW_VERSION
static const uint8_t _required_fw_version = FW_VERSION;

#if ENABLE_OLED
// ─── OLED ─────────────────────────────────────────────────────────────────────
// ESP32-C3 SuperMini: SSD1306 128×32, I2C on SDA=GPIO1, SCL=GPIO0, no RST pin
#define OLED_WIDTH   128
#define OLED_HEIGHT   32
#define OLED_ADDR   0x3C
#define OLED_SDA       1
#define OLED_SCL       0

static Adafruit_SSD1306 oled(OLED_WIDTH, OLED_HEIGHT, &Wire, -1);
#endif

// ─── Receive buffer (ISR → loop bridge) ───────────────────────────────────────
static volatile bool    _status_available   = false;
static volatile bool    _ota_fail_available = false;

static esp_now_status_t  _status_buffer;

// Runtime MAC table: index 0 = spot 0x01, populated on HELLO
static uint8_t g_spot_macs[NUM_SPOTS][6];
static uint8_t g_spot_fw[NUM_SPOTS];  // fw_version per spot, from HELLO

typedef struct {
    uint8_t mac[6];
    uint8_t fw_version;
    uint8_t spot_id;
} hello_event_t;

// Ring buffer for HELLO events — sized to absorb a full simultaneous boot burst.
#define HELLO_RING_SIZE 16
static hello_event_t     _hello_ring[HELLO_RING_SIZE];
static volatile uint8_t  _hello_head = 0;  // ISR writes here
static volatile uint8_t  _hello_tail = 0;  // loop reads here

typedef struct {
    uint8_t spot_id;
    uint8_t attempt;
} ota_fail_event_t;
static ota_fail_event_t _ota_fail_buffer;

// Last known state per spot (index 0 = spot 0x01)
static esp_now_status_t g_spot_state[NUM_SPOTS] = {};

// ─── Forward declarations ──────────────────────────────────────────────────────
static void addPeer(const uint8_t *mac);
static void sendCommand(uint8_t spot_id, uint8_t command, uint8_t brightness, uint16_t param = 0);
static void uart2_send_handshake(uint8_t spot_id, uint8_t fw_version);
#if ENABLE_OLED
static void updateOLED();
#endif

// ─── ESP-NOW callbacks ────────────────────────────────────────────────────────
static void onDataReceive(const uint8_t *mac, const uint8_t *data, int len) {
    if (len < (int)sizeof(espnow_header_t)) return;

    const espnow_header_t *hdr = (const espnow_header_t *)data;

    switch (hdr->msg_type) {
        case MSG_STATUS: {
            if (len < (int)sizeof(espnow_status_packet_t)) return;
            const espnow_status_packet_t *pkt = (const espnow_status_packet_t *)data;
            memcpy((void *)&_status_buffer, &pkt->status, sizeof(esp_now_status_t));
            _status_available = true;
            break;
        }
        case MSG_HELLO: {
            uint8_t next = (_hello_head + 1) % HELLO_RING_SIZE;
            if (next != _hello_tail) {  // drop if full (shouldn't happen with 8 slots)
                memcpy(_hello_ring[_hello_head].mac, hdr->mac, 6);
                _hello_ring[_hello_head].fw_version = hdr->fw_version;
                _hello_ring[_hello_head].spot_id    = hdr->attempt;
                _hello_head = next;
            }
            break;
        }
        case MSG_OTA_FAILED: {
            if (len < (int)sizeof(espnow_status_packet_t)) {
                // Just header — use mac to find spot_id
                // spot_id is encoded in attempt field (repurposed as spot_id here)
                _ota_fail_buffer.spot_id = hdr->attempt;
                _ota_fail_buffer.attempt = 0;
            } else {
                const espnow_status_packet_t *pkt = (const espnow_status_packet_t *)data;
                _ota_fail_buffer.spot_id = pkt->status.spot_id;
                _ota_fail_buffer.attempt = hdr->attempt;
            }
            _ota_fail_available = true;
            break;
        }
        default:
            break;
    }
}

static void onDataSent(const uint8_t *mac, esp_now_send_status_t status) {
    (void)mac; (void)status;
}

// ─── Provisioning: PMK from Kconfig → NVS ────────────────────────────────────
static bool hexCharToByte(char c, uint8_t &out) {
    if (c >= '0' && c <= '9') { out = c - '0';        return true; }
    if (c >= 'a' && c <= 'f') { out = c - 'a' + 10;   return true; }
    if (c >= 'A' && c <= 'F') { out = c - 'A' + 10;   return true; }
    return false;
}

static void provisioning_init() {
    Preferences prefs;

#if defined(CONFIG_PROV_FORCE_RESET) && CONFIG_PROV_FORCE_RESET
    // Force-overwrite NVS — use when changing the PMK after first flash.
    // Set -DCONFIG_PROV_FORCE_RESET=1 in platformio.ini build_flags, flash once,
    // then remove the flag and reflash to return to normal NVS-first behaviour.
    Serial.println("[PROV] FORCE RESET — clearing NVS credentials.");
    prefs.begin("espnow", false); prefs.clear(); prefs.end();
#endif

    prefs.begin("espnow", false);

    // Check if PMK already stored
    if (prefs.getBytesLength("pmk") == 16) {
        prefs.getBytes("pmk", _pmk, 16);
        Serial.println("[PROV] PMK loaded from NVS.");
    } else {
        // Write PMK from build_flags CONFIG_ESPNOW_PMK (32 hex chars → 16 bytes)
        const char *hex = CONFIG_ESPNOW_PMK;
        size_t hexlen = strlen(hex);
        if (hexlen != 32) {
            Serial.println("[ERR] CONFIG_ESPNOW_PMK must be 32 hex chars — check build_flags");
            while (true) delay(1000);
        }
        for (int i = 0; i < 16; i++) {
            uint8_t hi, lo;
            if (!hexCharToByte(hex[i * 2], hi) || !hexCharToByte(hex[i * 2 + 1], lo)) {
                Serial.println("[ERR] CONFIG_ESPNOW_PMK contains invalid hex — check build_flags");
                while (true) delay(1000);
            }
            _pmk[i] = (hi << 4) | lo;
        }
        prefs.putBytes("pmk", _pmk, 16);
        Serial.println("[PROV] PMK written to NVS from build_flags.");
    }
    prefs.end();
    Serial.print("[PROV] PMK: ");
    for (int i = 0; i < 16; i++) Serial.printf("%02X", _pmk[i]);
    Serial.println();

    // ── WiFi credentials (for OTA HTTP) ───────────────────────────────────────
    prefs.begin("wifi", false);
    if (!prefs.isKey("ssid")) {
        prefs.putString("ssid",     CONFIG_WIFI_SSID);
        prefs.putString("password", CONFIG_WIFI_PASSWORD);
        Serial.println("[PROV] WiFi credentials written to NVS from build_flags.");
    } else {
        Serial.println("[PROV] WiFi credentials loaded from NVS.");
    }
    prefs.end();

    Serial.printf("[PROV] Required slave fw_version: %d\n", _required_fw_version);
}

// ─── Helpers ──────────────────────────────────────────────────────────────────
static void addPeer(const uint8_t *mac) {
    if (esp_now_is_peer_exist(mac)) return;
    esp_now_peer_info_t peer = {};
    memcpy(peer.peer_addr, mac, 6);
    peer.channel = 0;

    // Check if this is the broadcast peer — broadcast cannot be encrypted
    bool is_broadcast = true;
    for (int i = 0; i < 6; i++) {
        if (mac[i] != 0xFF) { is_broadcast = false; break; }
    }
    if (is_broadcast) {
        peer.encrypt = false;
    } else {
        peer.encrypt = true;
        memcpy(peer.lmk, _pmk, 16);  // use PMK as LMK (shared key approach)
    }
    esp_now_add_peer(&peer);
}

static void buildCmdPacket(espnow_cmd_packet_t &pkt, uint8_t spot_id, uint8_t command, uint8_t brightness, uint16_t param = 0) {
    memset(&pkt, 0, sizeof(pkt));
    pkt.header.msg_type   = MSG_CMD;
    pkt.header.fw_version = FW_VERSION;
    pkt.header.attempt    = 0;
    // Leave mac[] zero — master MAC not needed by spots
    pkt.cmd.spot_id    = spot_id;
    pkt.cmd.command    = command;
    pkt.cmd.brightness = brightness;
    pkt.cmd.param      = param;
}

static void sendCommand(uint8_t spot_id, uint8_t command, uint8_t brightness, uint16_t param) {
    espnow_cmd_packet_t pkt;
    buildCmdPacket(pkt, spot_id, command, brightness, param);

    if (spot_id == 0xFF) {
        esp_now_send(BROADCAST_MAC, (uint8_t *)&pkt, sizeof(pkt));
    } else if (spot_id >= 0x01 && spot_id <= NUM_SPOTS) {
        const uint8_t *mac = g_spot_macs[spot_id - 1];
        if (mac[0] == 0 && mac[1] == 0 && mac[2] == 0) {
            Serial.printf("[ERR] Spot 0x%02X MAC not known yet — awaiting HELLO\n", spot_id);
            return;
        }
        esp_now_send(mac, (uint8_t *)&pkt, sizeof(pkt));
    } else {
        Serial.printf("[ERR] Invalid spot ID: 0x%02X\n", spot_id);
    }
}

static void sendWhois() {
    espnow_header_t pkt = {};
    pkt.msg_type   = MSG_WHOIS;
    pkt.fw_version = FW_VERSION;
    esp_now_send(BROADCAST_MAC, (uint8_t *)&pkt, sizeof(pkt));
    Serial.println("[BOOT] WHOIS broadcast — waiting for spots to re-announce");
}

static void sendOtaBroadcast(uint8_t target_version) {
    espnow_ota_packet_t pkt;
    memset(&pkt, 0, sizeof(pkt));
    pkt.header.msg_type      = MSG_OTA_NOW;
    pkt.header.fw_version    = FW_VERSION;
    pkt.header.attempt       = 0;
    pkt.target_version       = target_version;
    esp_now_send(BROADCAST_MAC, (uint8_t *)&pkt, sizeof(pkt));
    Serial.printf("[OTA] Broadcast OTA_NOW → target_version=%d\n", target_version);
}

static void sendAck(const uint8_t *mac) {
    espnow_header_t ack = {};
    ack.msg_type   = MSG_ACK;
    ack.fw_version = FW_VERSION;
    esp_now_send(mac, (uint8_t *)&ack, sizeof(ack));
}

static void sendReject(const uint8_t *mac, uint8_t target_version) {
    espnow_ota_packet_t pkt;
    memset(&pkt, 0, sizeof(pkt));
    pkt.header.msg_type   = MSG_REJECT;
    pkt.header.fw_version = FW_VERSION;
    pkt.target_version    = target_version;
    esp_now_send(mac, (uint8_t *)&pkt, sizeof(pkt));
}

// ─── HELLO handler (called from loop, not ISR) ────────────────────────────────
static void handleHello(const uint8_t *mac, uint8_t spot_fw_version, uint8_t spot_id) {
    char mac_str[18];
    snprintf(mac_str, sizeof(mac_str), "%02X:%02X:%02X:%02X:%02X:%02X",
             mac[0], mac[1], mac[2], mac[3], mac[4], mac[5]);

    Serial.printf("[HELLO] spot=0x%02X  MAC=%s  fw=%d  required=%d\n",
                  spot_id, mac_str, spot_fw_version, _required_fw_version);

    // Dynamically register peer with encryption if not already known
    if (!esp_now_is_peer_exist(mac)) {
        addPeer(mac);
        Serial.printf("[HELLO] New peer registered: %s\n", mac_str);
    }

    // Store spot_id → MAC + fw_version mapping in RAM
    if (spot_id >= 0x01 && spot_id <= NUM_SPOTS) {
        memcpy(g_spot_macs[spot_id - 1], mac, 6);
        g_spot_fw[spot_id - 1]            = spot_fw_version;
        g_spot_state[spot_id - 1].spot_id = spot_id;
    }

    // Small delay so the newly registered peer is ready before we send
    delay(5);

    if (spot_fw_version >= _required_fw_version) {
        sendAck(mac);
        Serial.printf("[HELLO] → ACK (fw ok)\n");
    } else {
        sendReject(mac, _required_fw_version);
        Serial.printf("[HELLO] → REJECT + OTA target=%d\n", _required_fw_version);
    }

    // Notify bridge (UART2) of handshake
    uart2_send_handshake(spot_id, spot_fw_version);

    // Refresh OLED immediately so newly discovered spots appear
#if ENABLE_OLED
    updateOLED();
#endif
}

#if ENABLE_OLED
// ─── OLED display ─────────────────────────────────────────────────────────────
// Shows the last received status for each known spot, 1 row per spot.
// Layout (128×32, 8px rows):
//   Row 0: "MASTER v29  LED SPOTS"
//   Row 1: separator line
//   Row 2..3: "S1 ON 255 24.3C v28"  (up to 2 spots)

static void updateOLED() {
    oled.clearDisplay();
    oled.setTextSize(1);
    oled.setTextColor(SSD1306_WHITE);

    // Header
    oled.setCursor(0, 0);
    char hdr[22];
    snprintf(hdr, sizeof(hdr), "MASTER v%-3d LED SPOTS", FW_VERSION);
    oled.print(hdr);
    oled.drawLine(0, 9, OLED_WIDTH - 1, 9, SSD1306_WHITE);

    // One row per spot that has reported in (max 2 rows on 128×32)
    int row = 0;
    for (int i = 0; i < NUM_SPOTS && row < 2; i++) {
        const esp_now_status_t &s = g_spot_state[i];
        if (s.spot_id == 0) continue;

        int y = 12 + row * 10;
        oled.setCursor(0, y);

        const char *state_icon =
            (s.thermal_state == STATE_PULSE)      ? "*" :
            (s.thermal_state == THERMAL_CRITICAL) ? "!" :
            (s.thermal_state == THERMAL_THROTTLE) ? "~" : " ";

        // "S1 ON 255 24.3C v29"  (21 chars max at size=1, 6px/char = 21 cols)
        char buf[24];
        snprintf(buf, sizeof(buf), "S%d %s%3d%5.1fC%sv%d",
                 s.spot_id,
                 s.is_on ? "ON " : "OFF",
                 s.brightness,
                 s.temperature,
                 state_icon,
                 g_spot_fw[i]);
        oled.print(buf);
        row++;
    }

    if (row == 0) {
        oled.setCursor(0, 20);
        oled.print("Waiting for spots...");
    }

    oled.display();
}
#endif

// ─── OTA (self-update from GitHub releases) ───────────────────────────────────
// URL: https://github.com/FaisalHussain95/esp32-espnow-led-spots/releases/download/v<N>/master_c3_v<N>.bin
#define MASTER_OTA_URL_FMT \
    "https://github.com/FaisalHussain95/esp32-espnow-led-spots/releases/download/v%d/master_c3_v%d.bin"

static void espnow_reinit() {
    WiFi.disconnect(true);
    WiFi.mode(WIFI_STA);
    esp_wifi_set_channel(ESPNOW_CHANNEL, WIFI_SECOND_CHAN_NONE);
    if (esp_now_init() != ESP_OK) {
        Serial.println("[ERR] ESP-NOW re-init failed after OTA");
        return;
    }
    esp_now_set_pmk(_pmk);
    esp_now_register_recv_cb(onDataReceive);
    esp_now_register_send_cb(onDataSent);
    addPeer(BROADCAST_MAC);
    // Re-register any known spot peers
    for (int i = 0; i < NUM_SPOTS; i++) {
        if (g_spot_macs[i][0] || g_spot_macs[i][1] || g_spot_macs[i][2]) {
            addPeer(g_spot_macs[i]);
        }
    }
    Serial.println("[ESPNOW] Re-initialised after OTA attempt");
    sendWhois();
}

static void master_ota_start(uint8_t target_version) {
    Serial.printf("[OTA] Master self-update to v%d\n", target_version);

    // Read WiFi creds from NVS
    Preferences prefs;
    prefs.begin("wifi", true);
    String ssid     = prefs.getString("ssid",     "");
    String password = prefs.getString("password", "");
    prefs.end();

    if (ssid.isEmpty()) {
        Serial.println("[OTA] No WiFi credentials in NVS — cannot self-update");
        espnow_reinit();
        return;
    }

    // Temporarily stop ESP-NOW and connect to WiFi
    esp_now_deinit();
    WiFi.mode(WIFI_STA);

    char url[200];
    snprintf(url, sizeof(url), MASTER_OTA_URL_FMT, target_version, target_version);

    httpUpdate.setLedPin(LED_BUILTIN, LOW);
    httpUpdate.setFollowRedirects(HTTPC_FORCE_FOLLOW_REDIRECTS);

    for (int attempt = 1; attempt <= 5; attempt++) {
        Serial.printf("[OTA] Attempt %d/5\n", attempt);

        // Connect (or reconnect) to WiFi each attempt
        if (WiFi.status() != WL_CONNECTED) {
            Serial.printf("[OTA] Connecting to WiFi '%s'", ssid.c_str());
            WiFi.begin(ssid.c_str(), password.c_str());
            uint32_t t0 = millis();
            while (WiFi.status() != WL_CONNECTED && millis() - t0 < 15000) {
                delay(500);
                Serial.print(".");
            }
            Serial.println();
        }

        if (WiFi.status() != WL_CONNECTED) {
            Serial.printf("[OTA] WiFi connect failed — SSID='%s' password='%s'\n",
                          ssid.c_str(), password.c_str());
            if (attempt < 5) {
                Serial.println("[OTA] Retrying in 10s...");
                delay(10000);
            }
            continue;
        }

        // Force Cloudflare DNS
        WiFi.config(WiFi.localIP(), WiFi.gatewayIP(), WiFi.subnetMask(),
                    IPAddress(1, 1, 1, 1), IPAddress(1, 0, 0, 1));

        WiFiClientSecure client;
        client.setInsecure();
        client.setHandshakeTimeout(30);
        t_httpUpdate_return ret = httpUpdate.update(client, url);

        switch (ret) {
            case HTTP_UPDATE_OK:
                Serial.println("[OTA] Update OK — rebooting");
                return;
            case HTTP_UPDATE_NO_UPDATES:
                Serial.println("[OTA] No update available");
                espnow_reinit();
                return;
            case HTTP_UPDATE_FAILED:
                Serial.printf("[OTA] Attempt %d failed: %s\n", attempt,
                              httpUpdate.getLastErrorString().c_str());
                if (attempt < 5) {
                    Serial.println("[OTA] Retrying in 10s...");
                    delay(10000);
                }
                break;
        }
    }

    Serial.println("[OTA] All attempts failed — staying on current firmware.");
    espnow_reinit();
}

// ─── UART2 bridge (to WiFi ESP32-B) ──────────────────────────────────────────
// Frame format (command, 6 bytes):  0xAA 0x01 spot_id brightness command 0x55
// Frame format (status,  9 bytes):  0xAA 0x02 spot_id brightness temp_hi temp_lo thermal_state is_on 0x55
//   temperature encoded as int16 in 0.1°C units (e.g. 24.3°C → 243)
// Frame format (version, 4 bytes):  0xAA 0x03 target_version 0x55
#define UART2_START     0xAA
#define UART2_END       0x55
#define UART2_CMD       0x01
#define UART2_STATUS    0x02
#define UART2_VERSION   0x03
#define UART2_HANDSHAKE 0x04

// Frame: 0xAA 0x04 spot_id fw_version 0x55
static void uart2_send_handshake(uint8_t spot_id, uint8_t fw_version) {
    uint8_t frame[5] = { UART2_START, UART2_HANDSHAKE, spot_id, fw_version, UART2_END };
    Serial1.write(frame, 5);
}

static void uart2_send_status(const esp_now_status_t &s) {
    int16_t temp_raw = (int16_t)(s.temperature * 10.0f);
    uint8_t frame[9];
    frame[0] = UART2_START;
    frame[1] = UART2_STATUS;
    frame[2] = s.spot_id;
    frame[3] = s.brightness;
    frame[4] = (uint8_t)(temp_raw >> 8);
    frame[5] = (uint8_t)(temp_raw & 0xFF);
    frame[6] = s.thermal_state;
    frame[7] = s.is_on ? 1 : 0;
    frame[8] = UART2_END;
    Serial1.write(frame, 9);
}

static uint8_t _u2buf[8];
static uint8_t _u2len = 0;
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
void loop() {
    // 1. Handle HELLO from spots (dynamic peer registration + version check)
    while (_hello_tail != _hello_head) {
        hello_event_t ev = _hello_ring[_hello_tail];
        _hello_tail = (_hello_tail + 1) % HELLO_RING_SIZE;
        handleHello(ev.mac, ev.fw_version, ev.spot_id);
    }

    // 2. Process received status packets
    if (_status_available) {
        _status_available = false;
        esp_now_status_t s;
        memcpy(&s, (const void *)&_status_buffer, sizeof(s));

        if (s.spot_id >= 0x01 && s.spot_id <= NUM_SPOTS) {
            const esp_now_status_t &prev = g_spot_state[s.spot_id - 1];

            // Boot packet: brightness=0, is_on=false, temp=0 — spot just rebooted.
            // Re-send the last known command so it restores its state.
            bool is_boot_packet = (!s.is_on && s.brightness == 0 && s.temperature == 0.0f);
            if (is_boot_packet && prev.spot_id != 0) {
                Serial.printf("[INFO] Spot 0x%02X rebooted — restoring state (%s bri=%d)\n",
                              s.spot_id, prev.is_on ? "ON" : "OFF", prev.brightness);
                if (prev.is_on) {
                    sendCommand(s.spot_id, CMD_TURN_ON, prev.brightness);
                } else {
                    sendCommand(s.spot_id, CMD_TURN_OFF, 0);
                }
            }

            g_spot_state[s.spot_id - 1] = s;
        }

        // Serial log
        const char *state_str =
            (s.thermal_state == STATE_PULSE)      ? "pulse" :
            (s.thermal_state == THERMAL_CRITICAL) ? "CRITICAL" :
            (s.thermal_state == THERMAL_THROTTLE) ? "THROTTLE" : "normal";
        Serial.printf("[STATUS] spot=0x%02X  %s  bri=%d  temp=%.1f°C  state=%s\n",
                      s.spot_id, s.is_on ? "ON " : "OFF",
                      s.brightness, s.temperature, state_str);

        uart2_send_status(s);
#if ENABLE_OLED
        updateOLED();
#endif
    }

    // 3. Log OTA failure notifications from spots
    if (_ota_fail_available) {
        _ota_fail_available = false;
        Serial.printf("[OTA] Spot 0x%02X reported OTA failure (attempt %d)\n",
                      _ota_fail_buffer.spot_id, _ota_fail_buffer.attempt);
    }

    // 4. Poll UART2 for incoming frames from WiFi ESP32-B
    uart2_poll();

    // 5. Yield to idle task — allows light-sleep between events, reduces heat
    delay(1);

    // 6. Accumulate serial input, process on newline
    while (Serial.available()) {
        char c = (char)Serial.read();
        if (c == '\n' || c == '\r') {
            if (_line_len > 0) {
                _line_buf[_line_len] = '\0';
                processLine(_line_buf);
                _line_len = 0;
            }
        } else if (_line_len < sizeof(_line_buf) - 1) {
            _line_buf[_line_len++] = c;
        }
    }
}

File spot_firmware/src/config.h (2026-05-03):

#pragma once
#include <stdint.h>

// ─── Identity ─────────────────────────────────────────────────────────────────
// SPOT_ID is set via CONFIG_SPOT_ID build flag in platformio.ini,
// written to NVS on first flash, and survives OTA updates.
// Use provisioning_get_spot_id() at runtime — do not use CONFIG_SPOT_ID directly.
extern uint8_t SPOT_ID;

// ─── GPIO Pin Assignments ─────────────────────────────────────────────────────
// ESP32 WROVER (prototype)
// #define PIN_PWM_OUT     18   // LEDC output → PT4115 DIM pin
// #define PIN_NTC_ADC     34   // ADC1_CH6, input-only pin — no internal pull
// #define PIN_STATUS_LED   2   // Onboard LED, active HIGH

// ESP32-C3 SuperMini (final)
#define PIN_PWM_OUT     10   // LEDC output → PT4115 DIM pin (no ADC, no strapping)
#define PIN_NTC_ADC      3   // ADC1_CH3 — safe with ESP-NOW/WiFi active (ADC1 only)
#define PIN_STATUS_LED   8   // Onboard blue LED, active LOW
#define STATUS_LED_ON   LOW  // GPIO8 onboard LED lights when driven LOW
#define STATUS_LED_OFF  HIGH

// ─── Fan Control ──────────────────────────────────────────────────────────────
#define PIN_FAN_PWM      4   // AO3400 gate — GPIO output drives fan MOSFET
#define PIN_FAN_EN       5   // MT3608 EN — drive HIGH to enable 5V boost rail

#define FAN_ON_TEMP     45.0f  // Turn fan on above this (°C)
#define FAN_OFF_TEMP    40.0f  // Turn fan off below this (°C) — hysteresis
#define FAN_BOOST_DELAY_MS  2  // Wait after enabling MT3608 before driving MOSFET

// ─── LEDC (PWM) Configuration ─────────────────────────────────────────────────
#define LEDC_CHANNEL     0
#define LEDC_TIMER       0
#define LEDC_FREQ_HZ  10000  // 10 kHz — inaudible, within PT4115 DIM pin range
#define LEDC_RESOLUTION  8   // 8-bit → duty range 0–255

// ─── NTC / ADC Configuration ──────────────────────────────────────────────────
#define ADC_SAMPLES       32       // Oversampling count to reduce noise
#define NTC_B_COEFF     3950.0f    // Beta coefficient
#define NTC_R0         10000.0f    // NTC nominal resistance at T0 (ohms)
#define NTC_T0          298.15f    // T0 in Kelvin (25°C)
#define NTC_R_PULLUP    5100.0f    // Fixed resistor to GND (5.1kΩ); NTC is on the 3.3V side
#define ADC_MAX_VALUE   4095.0f    // 12-bit ADC full scale

// ─── Thermal Thresholds (°C) ──────────────────────────────────────────────────
#define TEMP_NORMAL_MAX   60.0f    // Below this: full PWM authority
#define TEMP_THROTTLE_MAX 75.0f    // Above this: hard floor enforced
#define TEMP_CRITICAL     85.0f    // Above this: CRITICAL — alert master

// ─── Dimming Limits ───────────────────────────────────────────────────────────
#define PWM_MIN_FLOOR   20         // Minimum PWM in throttle/critical states
#define PWM_MAX        160         // ~5W operating point for COB LED

// ─── Timing (ms) ──────────────────────────────────────────────────────────────
#define THERMAL_CHECK_INTERVAL_MS  1000
#define STATUS_REPORT_INTERVAL_MS 10000  // Periodic unsolicited status to master
#define FADE_STEP_DELAY_MS           10
#define STATUS_LED_ON_MS           1000   // NORMAL state: LED on duration
#define STATUS_LED_OFF_MS          2000   // NORMAL state: LED off duration

// ─── ESP-NOW Radio ────────────────────────────────────────────────────────────
#define ESPNOW_CHANNEL  11   // WiFi channel for all ESP-NOW traffic (1, 6, or 11)

// ─── Firmware Version & OTA ───────────────────────────────────────────────────
#define FW_VERSION  31
#define OTA_MAX_ATTEMPTS  5
#define OTA_RETRY_DELAY_MS  10000
#define OTA_BASE_URL \
    "https://github.com/FaisalHussain95/esp32-espnow-led-spots/releases/download/v%d/slave_c3_supermini_v%d.bin"

// ─── ESP-NOW Message Types ────────────────────────────────────────────────────
#define MSG_HELLO       0x01  // slave → master: announce version (unencrypted OK)
#define MSG_ACK         0x02  // master → slave: version ok
#define MSG_REJECT      0x03  // master → slave: version outdated, OTA incoming
#define MSG_OTA_NOW     0x04  // master → all slaves: trigger OTA to target_version
#define MSG_OTA_FAILED  0x05  // slave → master: OTA attempt failed
#define MSG_WHOIS       0x06  // master → all slaves: re-announce yourself (broadcast on master boot)
#define MSG_CMD         0x10  // master → slave: LED command (wraps esp_now_cmd_t)
#define MSG_STATUS      0x11  // slave → master: status reply (wraps esp_now_status_t)

// ─── ESP-NOW Command Bytes (CMD_* used inside MSG_CMD payload) ────────────────
#define CMD_SET_BRIGHTNESS  0x01
#define CMD_TURN_ON         0x02
#define CMD_TURN_OFF        0x03
#define CMD_REQUEST_STATUS  0x04
#define CMD_PULSE           0x05

// ─── Thermal States ───────────────────────────────────────────────────────────
#define THERMAL_NORMAL    0
#define THERMAL_THROTTLE  1
#define THERMAL_CRITICAL  2
#define STATE_PULSE       3

// ─── ESP-NOW Packet Structures ────────────────────────────────────────────────
// Packed to prevent compiler padding from misaligning bytes on the wire.
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

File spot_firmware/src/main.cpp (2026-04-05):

#include <Arduino.h>
#include <WiFi.h>
#include "config.h"
#include "thermal.h"
#include "dimming.h"
#include "espnow_manager.h"
#include "provisioning.h"
#include "ota.h"

// ─── Global state ─────────────────────────────────────────────────────────────
uint8_t         SPOT_ID                = 0x01;  // Overwritten from NVS in setup()
static uint8_t  g_requested_brightness = PWM_MAX;  // Master's intended brightness
static bool     g_is_on                = true;     // Default ON — mains switch acts as power control
static float    g_temperature          = 0.0f;
static uint8_t  g_thermal_state        = THERMAL_NORMAL;
static uint32_t g_last_thermal_ms      = 0;
static uint32_t g_last_report_ms       = 0;
static bool     g_fan_on               = false;

// Pulse loop state
static bool     g_pulsing              = false;
static uint8_t  g_pulse_peak           = 100;
static uint16_t g_pulse_half_dur       = 250;  // half-cycle ms
static bool     g_pulse_rising         = true;
static uint32_t g_pulse_phase_start    = 0;

// ─── Forward declarations ─────────────────────────────────────────────────────
static void handleCommand(const esp_now_cmd_t &cmd);
static void runThermalPolicy();
static void runFanPolicy();
static void updateStatusLED();
static void processSerialCommands();

// ─── Setup ────────────────────────────────────────────────────────────────────
void setup() {
    Serial.begin(115200);
    delay(100);   // Minimal stabilisation delay — no USB CDC needed in production
    WiFi.mode(WIFI_STA);

    pinMode(PIN_STATUS_LED, OUTPUT);
    digitalWrite(PIN_STATUS_LED, STATUS_LED_OFF);

    // Fan GPIOs — both must be configured as outputs (PCB requirement)
    pinMode(PIN_FAN_EN,  OUTPUT);
    pinMode(PIN_FAN_PWM, OUTPUT);
    digitalWrite(PIN_FAN_EN,  LOW);   // MT3608 off at boot
    digitalWrite(PIN_FAN_PWM, LOW);   // MOSFET off at boot

    // Write PMK + WiFi creds + spot ID to NVS on first boot
    provisioning_init();
    SPOT_ID = provisioning_get_spot_id();

    Serial.printf("[BOOT] Spot node ID=0x%02X  FW_VERSION=%d  MAC=%s\n",
                  SPOT_ID, FW_VERSION, WiFi.macAddress().c_str());

    analogReadResolution(12);       // 12-bit → 0–4095
    analogRead(PIN_NTC_ADC);        // Dummy read to initialise the ADC channel
    analogSetPinAttenuation(PIN_NTC_ADC, ADC_11db);  // Now set 11dB (0–3.3V range)

    dimming_init();
    espnow_init();  // Loads PMK, enables encryption, sends MSG_HELLO to master

    // Default ON — fade in on boot so the light doesn't snap on abruptly
    fadeTo(g_requested_brightness, 1500);  // 1.5 s fade-in

    Serial.println("[BOOT] Ready.");
}

// ─── Main loop ────────────────────────────────────────────────────────────────
void loop() {
    uint32_t now = millis();

    // 1. Process incoming ESP-NOW commands
    esp_now_cmd_t cmd;
    if (espnow_getCommand(&cmd)) {
        handleCommand(cmd);
    }

    // 1b. Check for OTA trigger from master
    uint8_t ota_version = 0;
    if (espnow_getOtaTrigger(&ota_version)) {
        Serial.printf("[OTA] Triggered — target version %d\n", ota_version);
        ota_start(ota_version);  // Blocks until done or all retries fail
    }

    // 1c. Pulse loop — non-blocking linear ramp up/down
    if (g_pulsing) {
        uint32_t elapsed = now - g_pulse_phase_start;
        if (elapsed >= g_pulse_half_dur) {
            // Phase done — flip direction
            g_pulse_rising = !g_pulse_rising;
            g_pulse_phase_start = now;
            elapsed = 0;
        }
        uint8_t lo = PWM_MIN_FLOOR;
        uint8_t hi = g_pulse_peak;
        uint8_t val;
        if (g_pulse_rising) {
            val = lo + (uint8_t)((uint32_t)(hi - lo) * elapsed / g_pulse_half_dur);
        } else {
            val = hi - (uint8_t)((uint32_t)(hi - lo) * elapsed / g_pulse_half_dur);
        }
        setBrightness(val);
    }

    // 1d. Local serial commands (for bench testing without master)
    processSerialCommands();

    // 2. Thermal check every 1 second
    if (now - g_last_thermal_ms >= THERMAL_CHECK_INTERVAL_MS) {
        g_last_thermal_ms = now;
        runThermalPolicy();
    }

    // 3. Periodic status report to master every 10 seconds
    if (now - g_last_report_ms >= STATUS_REPORT_INTERVAL_MS) {
        g_last_report_ms = now;
        espnow_retryHelloIfNeeded();
        uint8_t report_bri   = g_pulsing ? g_pulse_peak : getBrightness();
        uint8_t report_state = g_pulsing ? STATE_PULSE : g_thermal_state;
        sendStatus(report_bri, g_temperature, report_state, g_is_on);
    }

    // 5. Status LED heartbeat (non-uniform timing handled inside)
    updateStatusLED();
}
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

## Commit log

2026-03-04 docs: switch to ESP32-C3 SuperMini + PT4115 CC driver at 24V
    - Replace ESP32-S2-MINI-1-N4 with ESP32-C3 SuperMini as final target MCU
    - Replace IRLZ44N MOSFET with PT4115 constant-current buck driver (Rsense=0.33Ω → 303mA)
    - Switch supply from HLK-PM15 (15V) to HLK-PM24 (24V)
    - Update GPIO assignments: PWM→GPIO10, NTC ADC→GPIO3, status LED→GPIO8 (active LOW)
    - Invert status LED logic in firmware via STATUS_LED_ON/OFF macros
    - Update platformio.ini board to esp32-c3-devkitm-1
    [diy_led_spot.kicad_pcb, diy_led_spot.kicad_sch]
2026-03-04 feat: Add KiCad project files for DIY LED Spot project
    - Created diy_led_spot_step5.kicad_prl with board settings, visibility options, and selection filters.
    - Created diy_led_spot_step5.kicad_pro with detailed design settings, net settings, and IPC2581 configurations.
    [diy_led_spot_step5.kicad_pcb]
2026-03-04 feat: Implement ESP-NOW OTA system with encryption and provisioning
    - Added OTA functionality to espnow_manager, allowing slaves to receive firmware updates.
    - Introduced provisioning module to handle PMK and WiFi credentials storage in NVS.
    - Updated espnow_manager to support encrypted communication using PMK.
    - Enhanced main firmware logic to trigger OTA updates and handle commands.
    - Created GitHub Actions workflow for automated builds and releases on version tags.
    - Added WiFi bridge firmware to facilitate communication between Home Assistant and LED spots.
    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
2026-03-14 feat: PID thermal, PWM_MAX cap, MSG_WHOIS; firmware OTA + provisioning + PID
    - README: rewrite thermal section to reflect PID controller (Kp=8, Ki=0.5, Kd=5),
    add PWM_MAX=100 hardware ceiling table, add MSG_WHOIS 0x06 to message types table
    - Spot firmware: OTA (HTTP from GitHub releases, 5-retry), provisioning (PMK + WiFi
    creds + spot ID from build_flags → NVS), PID thermal throttle, MSG_WHOIS support
    - Master firmware: UART2 bridge to WiFi ESP32-B, MSG_WHOIS broadcast on boot,
    dynamic peer registration, required fw version + OTA trigger via serial/UART2
    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
    [diy_led_spot_step5.kicad_pcb]
2026-03-14 feat: Fix OTA functionality
    [main.cpp, ota.cpp]
2026-03-14 feat: Enhance provisioning and ESPNOW error logging with PMK output
    [espnow_manager.cpp, main.cpp, provisioning.cpp]
2026-03-14 feat: Improve OTA update process with retry mechanism and enhanced error handling
    [main.cpp, ota.cpp]
2026-03-14 feat: bump to v7, fix PID dead-band, OTA DNS and ESP-NOW reinit
    [config.h]
2026-03-14 fix: OTA reliability, ESP-NOW broadcast HELLO, UART2 handshake notify
    [espnow_manager.cpp, main.cpp, ota.cpp]
2026-03-14 fix: remove NVS fw_version, add safety LED cutoff on master loss, bump to v9
    - Remove NVS-based _required_fw_version — use compile-time FW_VERSION
    directly, eliminating version desync after failed OTA
    - Spot: track consecutive ESP-NOW send failures, cut LED off after 5
    failures (safety: no uncontrolled LED operation without master)
    - Reset failure counter on successful send or any received packet
    [config.h, espnow_manager.cpp, main.cpp]
2026-03-14 fix: remove NVS fw_version, add safety LED cutoff on master loss, bump to v10
    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
    [config.h]
2026-03-14 feat: increase PWM_MAX to 120, bump to v11
2026-03-14 fix: revert PWM_MAX to 100, bump to v12
    [config.h]
2026-03-14 fix: force WiFi channel 1, remove RX debug log, bump to v13
    - Force ESP-NOW to channel 1 on both master and spot — fixes packets
    not arriving when auto-channel picks different channels per device
    [config.h, espnow_manager.cpp, main.cpp]
2026-03-14 fix: master OTA retry includes WiFi connect, restore channel after OTA, bump to v14
    - Move WiFi connect inside master OTA retry loop (5 attempts cover both
    WiFi and HTTP failures, matching spot behaviour)
    - Re-set WiFi channel 1 in espnow_reinit() after failed OTA
    [config.h, main.cpp]
2026-03-14 fix: OLED text alignment, bump to v15
    [config.h, main.cpp]
2026-03-15 fix: retry HELLO every 10s until master ACKs, bump to v16
    - Spot tracks whether master has ACKed via _hello_acked flag
    - Resends HELLO broadcast every 10s until any packet from master arrives
    - Fixes standalone boot race where initial HELLO is lost
    [config.h, espnow_manager.cpp, main.cpp]
2026-03-15 fix: reduce TX power to 10dBm for standalone 3.3V stability, bump to v17
    - Set esp_wifi_set_max_tx_power(40) to reduce TX current spikes that
    may cause voltage sag on standalone MP1584 3.3V supply
    - Print actual TX power on boot for debug
    [config.h, espnow_manager.cpp]
2026-03-15 feat: add pulse command, bump TX power to 13dBm, bump to v19
    - New CMD_PULSE (0x05): ramps brightness up then down over configurable
    duration (default 500ms). Usage: pulse <spot|all> [bri] [ms]
    - Add param field to esp_now_cmd_t for pulse duration
    - Increase TX power from 10dBm to 13dBm (esp_wifi_set_max_tx_power=52)
2026-03-15 fix: remove duplicate default argument in sendCommand
    [main.cpp]
2026-03-15 feat: pulse command loops continuously until stopped, bump to v20
    - Pulse is now non-blocking and loops indefinitely (ramp up/down)
    - Any other command (on/off/dim) cancels the pulse
    - Pulse ramps between PWM_MIN_FLOOR and peak brightness
2026-03-15 fix: report pulse peak brightness to master instead of fluctuating PWM, bump to v21
    [config.h, main.cpp]
2026-03-15 fix: remove PID controller, use simple linear throttle, bump to v23
    - Replace PID thermal controller with linear ramp-down between
    TEMP_NORMAL_MAX (60C) and TEMP_THROTTLE_MAX (75C)
    - Removes oscillation at 54C caused by PID reacting to noise
    - Remove TEMP_PID_TARGET, Kp/Ki/Kd config defines
    [config.h, main.cpp, thermal.cpp]
2026-03-15 docs: update README — remove PID, add pulse cmd, add fan improvement
    - Replace PID thermal section with linear throttle description
    - Add CMD_PULSE to protocol docs and serial CLI section
    - Remove NVS fw_version from NVS layout (no longer used)
    - Add planned active cooling (MT3608 + 25mm fan) to Next Steps
2026-03-21 kicad: save current PCB/schematic state including routed and step3 variants
    [diy_led_spot.kicad_sch, diy_led_spot_routed.kicad_pcb, diy_led_spot_step3.kicad_pcb]
2026-03-22 kicad: save current PCB/schematic state
    [diy_led_spot.kicad_sch]
2026-03-22 feat: add local serial command parser for bench testing without master
    Adds processSerialCommands() to the spot loop so the LED can be
    controlled directly from the serial monitor (on/off/dim/pulse/status)
    without needing an ESP-NOW master — useful for validating each PCB.
    Also updates COM port to COM9.
2026-03-31 feat: add active fan cooling support (MT3608 + AO3400)
    - GPIO5 enables MT3608 boost (3.3V → 5V) with 2ms startup delay
    - GPIO4 drives AO3400 MOSFET to switch fan ground
    - Fan ON ≥ 50°C, OFF ≤ 45°C (hysteresis), forced ON on NTC fault
    - Update CLAUDE.md with full 3-node architecture and new modules
    - Mark active cooling as done in README next steps
2026-03-31 feat: add PROV serial command + fan cooling, bump to v24
2026-04-04 feat: update PWM limits and fan control temperatures, set default boot state to ON
2026-05-01 feat: enhance documentation and improve spots discoverability
    [diy_led_spot_step3.kicad_pcb]
2026-05-01 feat: add detailed sequence diagram for ESP32 spot communication and OTA process
2026-05-01 feat: add mermaid diagram for ESP32 spot communication architecture
2026-05-02 feat: Set maximum TX power to reduce heat on C3 SuperMini
